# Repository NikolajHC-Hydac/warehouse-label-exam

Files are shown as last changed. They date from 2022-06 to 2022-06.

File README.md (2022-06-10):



<!-- PROJECT LOGO -->
<br />
<div align="center">
  <a href="https://github.com/HydacDK/New-Warehouse-Lables/tree/Prototype4">
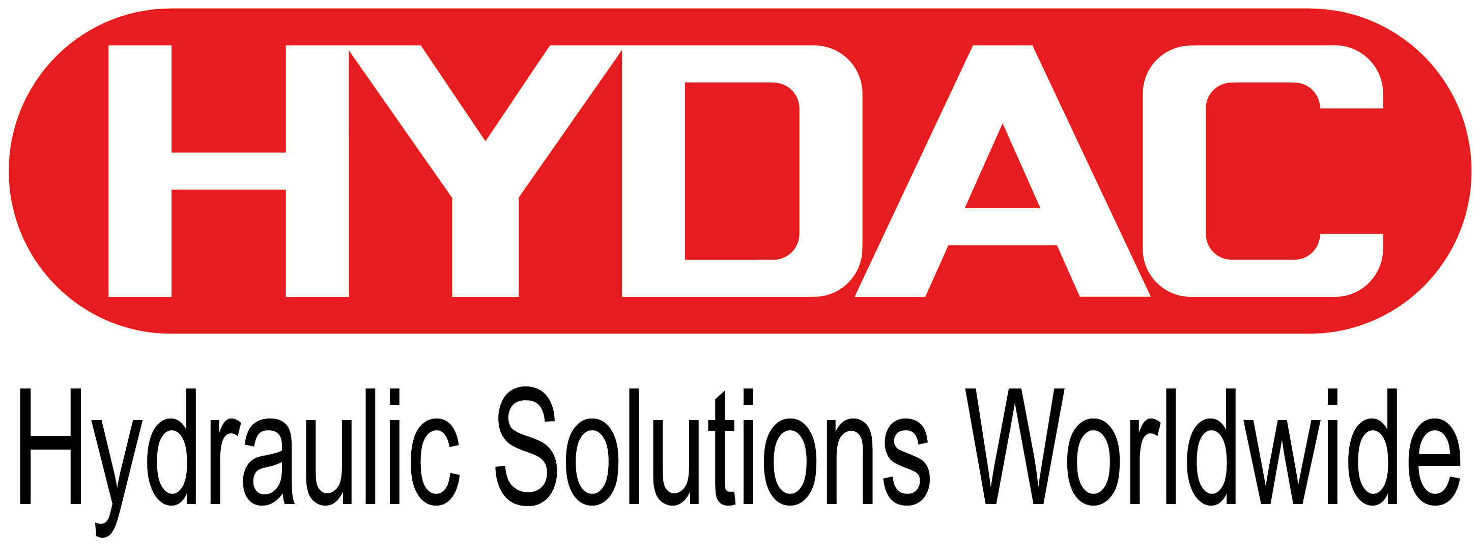
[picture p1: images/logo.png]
    
  </a>

<h3 align="center">Hydac DK Digital 1.0</h3>

  <p align="center">
    Box divided storage system controlled with buttons 
    <br />
    <a href="https://github.com/HydacDK/New-Warehouse-Lables/tree/Prototype4"><strong>Explore the docs »</strong></a>
    <br />
    <br />
    <a href="https://github.com/HydacDK/New-Warehouse-Lables/tree/Prototype4">View Demo</a>
    ·
    <a href="https://github.com/HydacDK/New-Warehouse-Lables/tree/Prototype4/issues">Report Bug</a>
    ·
    <a href="https://github.com/HydacDK/New-Warehouse-Lables/tree/Prototype4/issues">Request Feature</a>
  </p>
</div>

<!-- TABLE OF CONTENTS -->
<details>
  <summary>Table of Contents</summary>
  <ol>
    <li>
      <a href="#about-the-project">About The Project</a>
      <ul>
        <li><a href="#built-with">Built With</a></li>
      </ul>
    </li>
    <li>
      <a href="#getting-started">Getting Started</a>
      <ul>
        <li><a href="#prerequisites">Prerequisites</a></li>
        <li><a href="#installation">Installation</a></li>
      </ul>
    </li>
    <li><a href="#usage">Usage</a></li>
    <li><a href="#roadmap">Roadmap</a></li>
    <li><a href="#contact">Contact</a></li>
  </ol>
</details>

<!-- ABOUT THE PROJECT -->
## About The Project

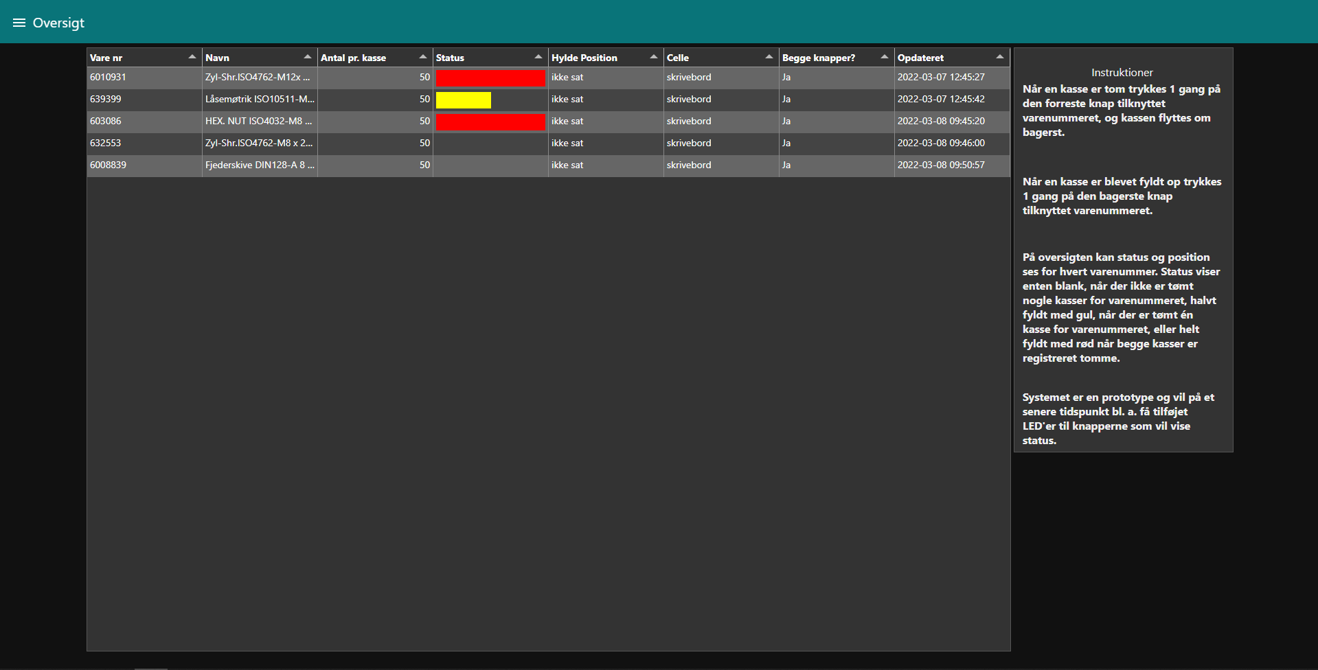
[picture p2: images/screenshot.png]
Product Name Screen Shot
[](http://localhost:1880/ui)

A simple box divided storage system, where two similar boxes with goods are placed on shelves. Buttons are placed on the front and back of the shelves, 2 push buttons for each pair of boxes. When a box is empty, the user presses the "order" on the front of the shelf, and the system notes on the reorder list that the box needs to be refilled. Once a week, the purchasing department will get a list of what c-items (bolts, washers and nuts) that needs to be ordered

Part goal:
C-items (bolts, washers and nuts) are ordered semi automatically by the user, system notes on the reorder list and sends it to the purchasing department weekly. Goods are stocked directly on the shelf.

Goal:
C-items (bolts, washers and nuts) ordered semi automatically by the user, and is sent directly to the distributor of said item. Items stocked directly on the shelf, and ready to use, without the purchasing department using resources on the process. Every month, the purchasing department will receive an invoice, while responsibility for the stock is outsourced to the user.

Gain:
It provides gain on all shelves: Purchasing, finance and user have fewer hours of administration in connection with ordering, invoicing, status, etc. Warehouse spends less time on transport to and from the warehouse and less time on searching for the goods. In addition, the standard program always contains the relevant items in appropriate quantities, and we can therefore cut back on both purchasing and stock binding.

<p align="right">(<a href="#top">back to top</a>)</p>

### Built With

* [Node-red](https://nodered.org/)
* [C++](https://isocpp.org/)
* [SQLite](https://www.sqlite.org/index.html)

<p align="right">(<a href="#top">back to top</a>)</p>

<!-- GETTING STARTED -->
## Getting Started

To get a local copy up and running follow these simple steps.

### Prerequisites

#### Debian and ubuntu based linux distributions  

* Node.js / npm
  ```sh
  # Using Ubuntu  
  curl -fsSL https://deb.nodesource.com/setup_14.x | sudo -E bash -
  sudo apt-get install -y nodejs

  # Using Debian, as root
  curl -fsSL https://deb.nodesource.com/setup_14.x | bash -
  apt-get install -y nodejs
  ```

* Node-red
  ```sh
  sudo npm install -g --unsafe-perm node-red
  ```  

#### Windows

* Node.js
  ```markdown
  Download a 64 or 32 bit version of node.js at [https://nodejs.org](https://nodejs.org/download/release/v14.19.1/)  
  Run the downloaded MSI file.  
    
  Once installed, open a command prompt and run the following command to ensure Node.js and npm are installed correctly.

  Using Powershell: node --version; npm --version

  Using cmd: node --version && npm --version
  ```  

* Node-red
  ```sh
  npm install -g --unsafe-perm node-red
  ```

### Installation

1. Clone the repo
   ```sh
   git clone https://github.com/HydacDK/New-Warehouse-Lables/tree/Prototype4.git
   ```
2. Build and upload esp32 code to control board 
3. Start node-red
    ```sh
    node-red
    ```
4. Import the "Flows.json" file using the node-red GUI
5. Install missing node-red modules
6. Set up mqtt server in the "MQTT" flow
7. In the "Database" flow, point the sqlite and watch nodes to the location of warehouselabels.db
8. Go to http://localhost:1880/ui, or wherever your node-red instance is hosted, enter the setup page, and add the email you want to receive updates on.

<p align="right">(<a href="#top">back to top</a>)</p>

<!-- USAGE EXAMPLES -->
## Usage

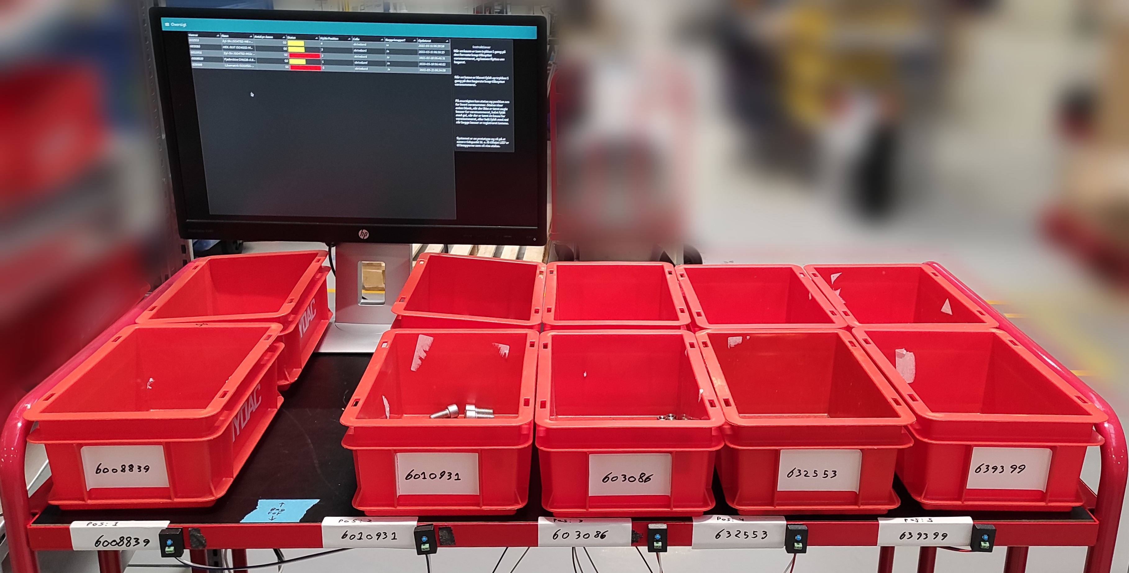
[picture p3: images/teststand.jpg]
TestStand


Buttons are placed in the front of every box pair on shelves, as well as behind them.  
Product numbers are then added to the database, and paired with their respective buttons, either by manually adding them using the setup page in the UI, or by importing them using a CSV file.  
When a box has been emptied, the user presses the matching front button once, and puts the box back in the back of the shelf.  
When the boxes are refilled, the user that is refilling the box, presses the matching button on the back of the shelf, to indicate to the system that the box has been filled again.

_For more examples, please refer to the [Documentation](https://example.com)_

<p align="right">(<a href="#top">back to top</a>)</p>

<!-- ROADMAP -->
## Roadmap

- [x] LED's on front buttons, showing the inventory status to the user
- [x] Automated opening of the UI after a system reset
- [x] Control board revision 4 PCB
    - [x] Design
    - [x] Order
    - [ ] Test
- [x] Buttons PCB
    - [x] Design
    - [x] Order
    - [x] Test

See the [open issues](https://github.com/HydacDK/New-Warehouse-Lables/issues) for a full list of proposed features (and known issues).

<p align="right">(<a href="#top">back to top</a>)</p>

<!-- CONTACT -->
## Contact

Linkedin: Nikolaj Hult-Christensen - [/in/nikolajhult](https://linkedin.com/in/nikolajhult)  
Email: Nikolaj.Hult-Christensen@hydac.dk  
Element: @hultn:hydac.com

Project Link: [https://github.com/HydacDK/New-Warehouse-Lables/tree/Prototype4](https://github.com/HydacDK/New-Warehouse-Lables/tree/Prototype4)

<p align="right">(<a href="#top">back to top</a>)</p>

<!-- MARKDOWN LINKS & IMAGES -->
<!-- https://www.markdownguide.org/basic-syntax/#reference-style-links -->
[contributors-shield]: https://img.shields.io/github/contributors/HydacDK/New-WarehouseLabels.svg?style=for-the-badge
[contributors-url]: https://github.com/HydacDK/New-WarehouseLabels/graphs/contributors
[forks-shield]: https://img.shields.io/github/forks/HydacDK/New-Warehouse-Lables/tree/Prototype4.svg?style=for-the-badge
[forks-url]: https://github.com/HydacDK/New-Warehouse-Lables/tree/Prototype4/network/members
[stars-shield]: https://img.shields.io/github/stars/HydacDK/New-Warehouse-Lables/tree/Prototype4.svg?style=for-the-badge
[stars-url]: https://github.com/HydacDK/New-Warehouse-Lables/tree/Prototype4/stargazers
[issues-shield]: https://img.shields.io/github/issues/HydacDK/New-Warehouse-Lables/tree/Prototype4.svg?style=for-the-badge
[issues-url]: https://github.com/HydacDK/New-Warehouse-Lables/tree/Prototype4/issues
[license-shield]: https://img.shields.io/github/license/HydacDK/New-Warehouse-Lables/tree/Prototype4.svg?style=for-the-badge
[license-url]: https://github.com/HydacDK/New-Warehouse-Lables/tree/Prototype4/blob/master/LICENSE.txt
[linkedin-shield]: https://img.shields.io/badge/-LinkedIn-black.svg?style=for-the-badge&logo=linkedin&colorB=555
[linkedin-url]: https://linkedin.com/in/linkedin_username
[product-screenshot]: images/screenshot.png
[test-stand]: images/teststand.jpg

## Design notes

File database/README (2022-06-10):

Import flows.json into an instance of node-red and deploy

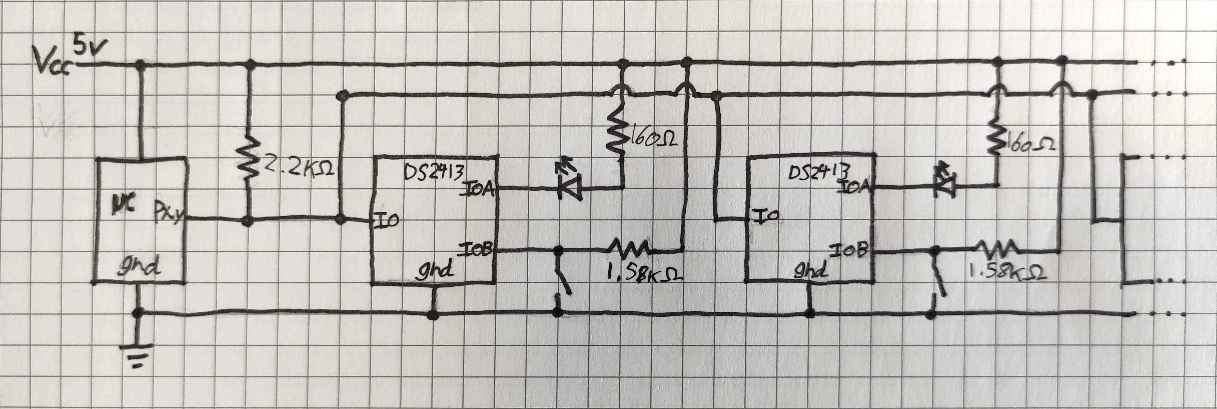
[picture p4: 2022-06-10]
images/onewire_switch_schematic.jpg

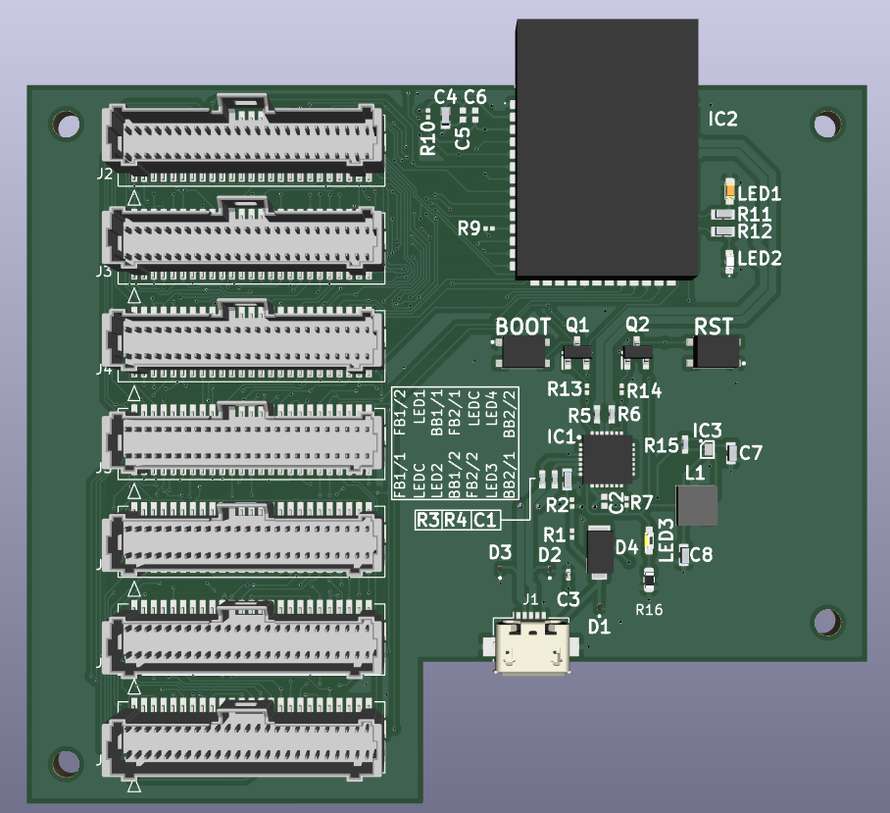
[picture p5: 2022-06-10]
images/pcb_front.png

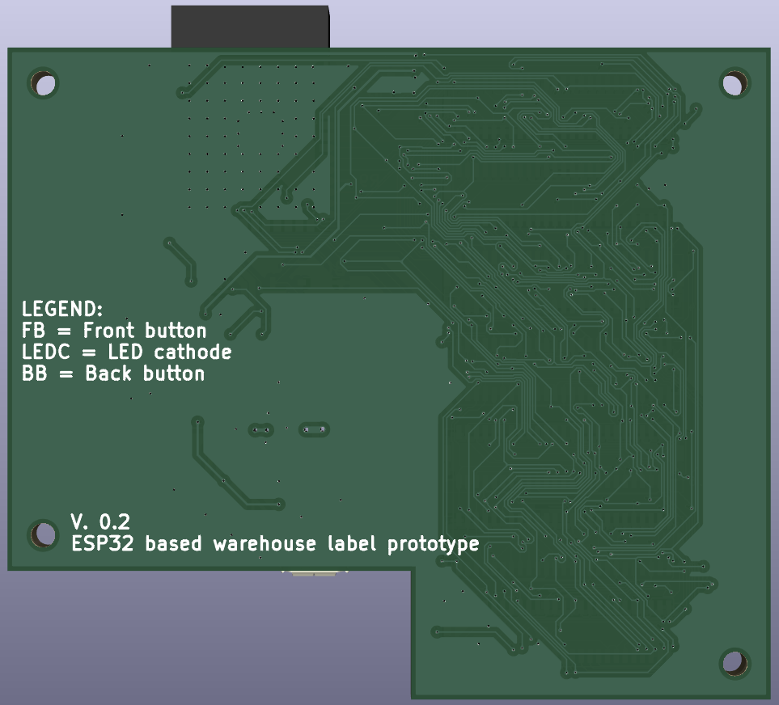
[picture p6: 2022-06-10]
images/pcb_back.png

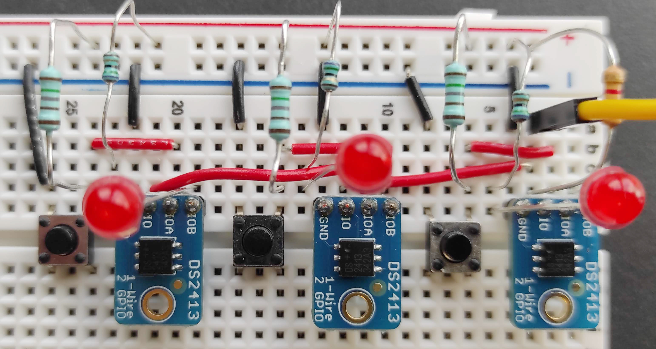
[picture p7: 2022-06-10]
images/onewire_switch_breadboard.jpg

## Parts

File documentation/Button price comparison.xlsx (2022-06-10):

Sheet: Comparison
 | Charlieplexing |  |  |  |  |  | Onewire + neopixel |  |  |  |  |  | Resistor ladder
Buttons: | Button price: | Wires: | Wire length: | Wire price: | charlie price: | Buttons: | Button price: | Wires: | Wire length: | Wire price: | 1-wire price: | Buttons: | Button price: | Wires: | Wire length: | Wire price: | Ladder price: |  |  | Nedenstående priser er kun for komponenter
1 | 8.88 kr. | 3.5 | 5.25 | 3.97 kr. | 12.85 kr. | 1 | 14.52 kr. | 1.5 | 14.3 | 10.81 kr. | 25.32 kr. | 1 | 9.62 kr. | 1.5 | 14.3 | 10.81 kr. | 20.42 kr. | Charlie plexing buttons: |  |  | Ledninger: | Længde: | Pris: | Pris pr. M:
2 | 17.77 kr. | 7 | 10.5 | 7.93 kr. | 25.70 kr. | 2 | 29.04 kr. | 3 | 14.6 | 11.03 kr. | 40.07 kr. | 2 | 19.23 kr. | 3 | 14.6 | 11.03 kr. | 30.26 kr. | Avg wire length: | 1.5 | m | RS PRO 0,13 brun | 100 | 62.55 | 0.6255
3 | 26.65 kr. | 10.5 | 15.75 | 11.90 kr. | 38.55 kr. | 3 | 43.56 kr. | 4.5 | 14.9 | 11.26 kr. | 54.82 kr. | 3 | 28.85 kr. | 4.5 | 14.9 | 11.26 kr. | 40.11 kr. | LED button wires: | 5 |  | RS PRO 0,13 Orange | 100 | 81.99 | 0.8199
4 | 35.53 kr. | 14 | 21 | 15.87 kr. | 51.40 kr. | 4 | 58.08 kr. | 6 | 15.2 | 11.49 kr. | 69.56 kr. | 4 | 38.46 kr. | 6 | 15.2 | 11.49 kr. | 49.95 kr. | LED button price: | 12.462 | kr | RS PRO 0,13 Rød | 100 | 82.15 | 0.8215
5 | 44.42 kr. | 17.5 | 26.25 | 19.84 kr. | 64.25 kr. | 5 | 72.60 kr. | 7.5 | 15.5 | 11.71 kr. | 84.31 kr. | 5 | 48.08 kr. | 7.5 | 15.5 | 11.71 kr. | 59.79 kr. | Button wires: | 2
6 | 53.30 kr. | 21 | 31.5 | 23.80 kr. | 77.10 kr. | 6 | 87.11 kr. | 9 | 15.8 | 11.94 kr. | 99.05 kr. | 6 | 57.70 kr. | 9 | 15.8 | 11.94 kr. | 69.64 kr. | Button price: | 5.30472 | kr | Avg: | 100 | 75.56 | 0.76
7 | 62.18 kr. | 24.5 | 36.75 | 27.77 kr. | 89.95 kr. | 7 | 101.63 kr. | 10.5 | 16.1 | 12.17 kr. | 113.80 kr. | 7 | 67.31 kr. | 10.5 | 16.1 | 12.17 kr. | 79.48 kr. | Avg wires: | 3.5
8 | 71.07 kr. | 28 | 42 | 31.74 kr. | 102.80 kr. | 8 | 116.15 kr. | 12 | 16.4 | 12.39 kr. | 128.55 kr. | 8 | 76.93 kr. | 12 | 16.4 | 12.39 kr. | 89.32 kr. | Avg button price: | 8.88336 | kr
9 | 79.95 kr. | 31.5 | 47.25 | 35.70 kr. | 115.65 kr. | 9 | 130.67 kr. | 13.5 | 16.7 | 12.62 kr. | 143.29 kr. | 9 | 86.55 kr. | 13.5 | 16.7 | 12.62 kr. | 99.16 kr.
10 | 88.83 kr. | 35 | 52.5 | 39.67 kr. | 128.50 kr. | 10 | 145.19 kr. | 15 | 17 | 12.85 kr. | 158.04 kr. | 10 | 96.16 kr. | 15 | 17 | 12.85 kr. | 109.01 kr.
11 | 97.72 kr. | 38.5 | 57.75 | 43.64 kr. | 141.35 kr. | 11 | 159.71 kr. | 16.5 | 17.3 | 13.07 kr. | 172.78 kr. | 11 | 105.78 kr. | 16.5 | 17.3 | 13.07 kr. | 118.85 kr.
12 | 106.60 kr. | 42 | 63 | 47.60 kr. | 154.21 kr. | 12 | 174.23 kr. | 18 | 17.6 | 13.30 kr. | 187.53 kr. | 12 | 115.39 kr. | 18 | 17.6 | 13.30 kr. | 128.69 kr.
13 | 115.48 kr. | 45.5 | 68.25 | 51.57 kr. | 167.06 kr. | 13 | 188.75 kr. | 19.5 | 17.9 | 13.53 kr. | 202.27 kr. | 13 | 125.01 kr. | 19.5 | 17.9 | 13.53 kr. | 138.54 kr. | Onewire + neopixel:
14 | 124.37 kr. | 49 | 73.5 | 55.54 kr. | 179.91 kr. | 14 | 203.27 kr. | 21 | 18.2 | 13.75 kr. | 217.02 kr. | 14 | 134.63 kr. | 21 | 18.2 | 13.75 kr. | 148.38 kr. | Avg wire length: | 0.20 | m
15 | 133.25 kr. | 52.5 | 78.75 | 59.51 kr. | 192.76 kr. | 15 | 217.79 kr. | 22.5 | 18.5 | 13.98 kr. | 231.77 kr. | 15 | 144.24 kr. | 22.5 | 18.5 | 13.98 kr. | 158.22 kr. | LED button wires: | 2
16 | 142.13 kr. | 56 | 84 | 63.47 kr. | 205.61 kr. | 16 | 232.31 kr. | 24 | 18.8 | 14.21 kr. | 246.51 kr. | 16 | 153.86 kr. | 24 | 18.8 | 14.21 kr. | 168.07 kr. | LED button price: | 19.06128 | kr
17 | 151.02 kr. | 59.5 | 89.25 | 67.44 kr. | 218.46 kr. | 17 | 246.83 kr. | 25.5 | 19.1 | 14.43 kr. | 261.26 kr. | 17 | 163.48 kr. | 25.5 | 19.1 | 14.43 kr. | 177.91 kr. | Button wires: | 1
18 | 159.90 kr. | 63 | 94.5 | 71.41 kr. | 231.31 kr. | 18 | 261.34 kr. | 27 | 19.4 | 14.66 kr. | 276.00 kr. | 18 | 173.09 kr. | 27 | 19.4 | 14.66 kr. | 187.75 kr. | Button price: | 9.97704 | kr
19 | 168.78 kr. | 66.5 | 99.75 | 75.37 kr. | 244.16 kr. | 19 | 275.86 kr. | 28.5 | 19.7 | 14.89 kr. | 290.75 kr. | 19 | 182.71 kr. | 28.5 | 19.7 | 14.89 kr. | 197.59 kr. | Avg wires: | 1.5
20 | 177.67 kr. | 70 | 105 | 79.34 kr. | 257.01 kr. | 20 | 290.38 kr. | 30 | 20 | 15.11 kr. | 305.50 kr. | 20 | 192.32 kr. | 30 | 20 | 15.11 kr. | 207.44 kr. | Avg button price: | 14.51916 | kr
21 | 186.55 kr. | 73.5 | 110.25 | 83.31 kr. | 269.86 kr. | 21 | 304.90 kr. | 31.5 | 20.3 | 15.34 kr. | 320.24 kr. | 21 | 201.94 kr. | 31.5 | 20.3 | 15.34 kr. | 217.28 kr. | Fixed amount of wire | 14 | ca. 14 meter ledning som skal trækkes x1 pr. Reol (GND)
22 | 195.43 kr. | 77 | 115.5 | 87.28 kr. | 282.71 kr. | 22 | 319.42 kr. | 33 | 20.6 | 15.57 kr. | 334.99 kr. | 22 | 211.56 kr. | 33 | 20.6 | 15.57 kr. | 227.12 kr.
23 | 204.32 kr. | 80.5 | 120.75 | 91.24 kr. | 295.56 kr. | 23 | 333.94 kr. | 34.5 | 20.9 | 15.79 kr. | 349.73 kr. | 23 | 221.17 kr. | 34.5 | 20.9 | 15.79 kr. | 236.97 kr.
24 | 213.20 kr. | 84 | 126 | 95.21 kr. | 308.41 kr. | 24 | 348.46 kr. | 36 | 21.2 | 16.02 kr. | 364.48 kr. | 24 | 230.79 kr. | 36 | 21.2 | 16.02 kr. | 246.81 kr. | Resistor ladder + neopixel:
25 | 222.08 kr. | 87.5 | 131.25 | 99.18 kr. | 321.26 kr. | 25 | 362.98 kr. | 37.5 | 21.5 | 16.25 kr. | 379.23 kr. | 25 | 240.41 kr. | 37.5 | 21.5 | 16.25 kr. | 256.65 kr. | Avg wire length: | 0.20 | m
26 | 230.97 kr. | 91 | 136.5 | 103.14 kr. | 334.11 kr. | 26 | 377.50 kr. | 39 | 21.8 | 16.47 kr. | 393.97 kr. | 26 | 250.02 kr. | 39 | 21.8 | 16.47 kr. | 266.49 kr. | LED button wires: | 2
27 | 239.85 kr. | 94.5 | 141.75 | 107.11 kr. | 346.96 kr. | 27 | 392.02 kr. | 40.5 | 22.1 | 16.70 kr. | 408.72 kr. | 27 | 259.64 kr. | 40.5 | 22.1 | 16.70 kr. | 276.34 kr. | LED button price: | 14.15832 | kr
28 | 248.73 kr. | 98 | 147 | 111.08 kr. | 359.81 kr. | 28 | 406.54 kr. | 42 | 22.4 | 16.93 kr. | 423.46 kr. | 28 | 269.25 kr. | 42 | 22.4 | 16.93 kr. | 286.18 kr. | Button wires: | 1
29 | 257.62 kr. | 101.5 | 152.25 | 115.05 kr. | 372.66 kr. | 29 | 421.06 kr. | 43.5 | 22.7 | 17.15 kr. | 438.21 kr. | 29 | 278.87 kr. | 43.5 | 22.7 | 17.15 kr. | 296.02 kr. | Button price: | 5.07408 | kr
30 | 266.50 kr. | 105 | 157.5 | 119.01 kr. | 385.51 kr. | 30 | 435.57 kr. | 45 | 23 | 17.38 kr. | 452.95 kr. | 30 | 288.49 kr. | 45 | 23 | 17.38 kr. | 305.87 kr. | Avg wires: | 1.5
31 | 275.38 kr. | 108.5 | 162.75 | 122.98 kr. | 398.36 kr. | 31 | 450.09 kr. | 46.5 | 23.3 | 17.61 kr. | 467.70 kr. | 31 | 298.10 kr. | 46.5 | 23.3 | 17.61 kr. | 315.71 kr. | Avg button price: | 9.6162 | kr
32 | 284.27 kr. | 112 | 168 | 126.95 kr. | 411.21 kr. | 32 | 464.61 kr. | 48 | 23.6 | 17.83 kr. | 482.45 kr. | 32 | 307.72 kr. | 48 | 23.6 | 17.83 kr. | 325.55 kr. | Fixed amount of wire | 14 | ca. 14 meter ledning som skal trækkes x1 pr. Reol (GND)
33 | 293.15 kr. | 115.5 | 173.25 | 130.91 kr. | 424.06 kr. | 33 | 479.13 kr. | 49.5 | 23.9 | 18.06 kr. | 497.19 kr. | 33 | 317.33 kr. | 49.5 | 23.9 | 18.06 kr. | 335.39 kr.
34 | 302.03 kr. | 119 | 178.5 | 134.88 kr. | 436.91 kr. | 34 | 493.65 kr. | 51 | 24.2 | 18.29 kr. | 511.94 kr. | 34 | 326.95 kr. | 51 | 24.2 | 18.29 kr. | 345.24 kr.
35 | 310.92 kr. | 122.5 | 183.75 | 138.85 kr. | 449.77 kr. | 35 | 508.17 kr. | 52.5 | 24.5 | 18.51 kr. | 526.68 kr. | 35 | 336.57 kr. | 52.5 | 24.5 | 18.51 kr. | 355.08 kr.
36 | 319.80 kr. | 126 | 189 | 142.81 kr. | 462.62 kr. | 36 | 522.69 kr. | 54 | 24.8 | 18.74 kr. | 541.43 kr. | 36 | 346.18 kr. | 54 | 24.8 | 18.74 kr. | 364.92 kr.
37 | 328.68 kr. | 129.5 | 194.25 | 146.78 kr. | 475.47 kr. | 37 | 537.21 kr. | 55.5 | 25.1 | 18.97 kr. | 556.18 kr. | 37 | 355.80 kr. | 55.5 | 25.1 | 18.97 kr. | 374.77 kr.
38 | 337.57 kr. | 133 | 199.5 | 150.75 kr. | 488.32 kr. | 38 | 551.73 kr. | 57 | 25.4 | 19.19 kr. | 570.92 kr. | 38 | 365.42 kr. | 57 | 25.4 | 19.19 kr. | 384.61 kr.
39 | 346.45 kr. | 136.5 | 204.75 | 154.72 kr. | 501.17 kr. | 39 | 566.25 kr. | 58.5 | 25.7 | 19.42 kr. | 585.67 kr. | 39 | 375.03 kr. | 58.5 | 25.7 | 19.42 kr. | 394.45 kr.
40 | 355.33 kr. | 140 | 210 | 158.68 kr. | 514.02 kr. | 40 | 580.77 kr. | 60 | 26 | 19.65 kr. | 600.41 kr. | 40 | 384.65 kr. | 60 | 26 | 19.65 kr. | 404.29 kr.
41 | 364.22 kr. | 143.5 | 215.25 | 162.65 kr. | 526.87 kr. | 41 | 595.29 kr. | 61.5 | 26.3 | 19.87 kr. | 615.16 kr. | 41 | 394.26 kr. | 61.5 | 26.3 | 19.87 kr. | 414.14 kr.
42 | 373.10 kr. | 147 | 220.5 | 166.62 kr. | 539.72 kr. | 42 | 609.80 kr. | 63 | 26.6 | 20.10 kr. | 629.90 kr. | 42 | 403.88 kr. | 63 | 26.6 | 20.10 kr. | 423.98 kr.
43 | 381.98 kr. | 150.5 | 225.75 | 170.58 kr. | 552.57 kr. | 43 | 624.32 kr. | 64.5 | 26.9 | 20.33 kr. | 644.65 kr. | 43 | 413.50 kr. | 64.5 | 26.9 | 20.33 kr. | 433.82 kr.
44 | 390.87 kr. | 154 | 231 | 174.55 kr. | 565.42 kr. | 44 | 638.84 kr. | 66 | 27.2 | 20.55 kr. | 659.40 kr. | 44 | 423.11 kr. | 66 | 27.2 | 20.55 kr. | 443.67 kr.
45 | 399.75 kr. | 157.5 | 236.25 | 178.52 kr. | 578.27 kr. | 45 | 653.36 kr. | 67.5 | 27.5 | 20.78 kr. | 674.14 kr. | 45 | 432.73 kr. | 67.5 | 27.5 | 20.78 kr. | 453.51 kr.
46 | 408.63 kr. | 161 | 241.5 | 182.49 kr. | 591.12 kr. | 46 | 667.88 kr. | 69 | 27.8 | 21.01 kr. | 688.89 kr. | 46 | 442.35 kr. | 69 | 27.8 | 21.01 kr. | 463.35 kr.
47 | 417.52 kr. | 164.5 | 246.75 | 186.45 kr. | 603.97 kr. | 47 | 682.40 kr. | 70.5 | 28.1 | 21.23 kr. | 703.63 kr. | 47 | 451.96 kr. | 70.5 | 28.1 | 21.23 kr. | 473.19 kr.
48 | 426.40 kr. | 168 | 252 | 190.42 kr. | 616.82 kr. | 48 | 696.92 kr. | 72 | 28.4 | 21.46 kr. | 718.38 kr. | 48 | 461.58 kr. | 72 | 28.4 | 21.46 kr. | 483.04 kr.
49 | 435.28 kr. | 171.5 | 257.25 | 194.39 kr. | 629.67 kr. | 49 | 711.44 kr. | 73.5 | 28.7 | 21.69 kr. | 733.13 kr. | 49 | 471.19 kr. | 73.5 | 28.7 | 21.69 kr. | 492.88 kr.
50 | 444.17 kr. | 175 | 262.5 | 198.35 kr. | 642.52 kr. | 50 | 725.96 kr. | 75 | 29 | 21.91 kr. | 747.87 kr. | 50 | 480.81 kr. | 75 | 29 | 21.91 kr. | 502.72 kr.
51 | 453.05 kr. | 178.5 | 267.75 | 202.32 kr. | 655.37 kr. | 51 | 740.48 kr. | 76.5 | 29.3 | 22.14 kr. | 762.62 kr. | 51 | 490.43 kr. | 76.5 | 29.3 | 22.14 kr. | 512.57 kr.
52 | 461.93 kr. | 182 | 273 | 206.29 kr. | 668.22 kr. | 52 | 755.00 kr. | 78 | 29.6 | 22.37 kr. | 777.36 kr. | 52 | 500.04 kr. | 78 | 29.6 | 22.37 kr. | 522.41 kr.
53 | 470.82 kr. | 185.5 | 278.25 | 210.25 kr. | 681.07 kr. | 53 | 769.52 kr. | 79.5 | 29.9 | 22.59 kr. | 792.11 kr. | 53 | 509.66 kr. | 79.5 | 29.9 | 22.59 kr. | 532.25 kr.
54 | 479.70 kr. | 189 | 283.5 | 214.22 kr. | 693.92 kr. | 54 | 784.03 kr. | 81 | 30.2 | 22.82 kr. | 806.85 kr. | 54 | 519.27 kr. | 81 | 30.2 | 22.82 kr. | 542.09 kr.
55 | 488.58 kr. | 192.5 | 288.75 | 218.19 kr. | 706.77 kr. | 55 | 798.55 kr. | 82.5 | 30.5 | 23.05 kr. | 821.60 kr. | 55 | 528.89 kr. | 82.5 | 30.5 | 23.05 kr. | 551.94 kr.
56 | 497.47 kr. | 196 | 294 | 222.16 kr. | 719.62 kr. | 56 | 813.07 kr. | 84 | 30.8 | 23.27 kr. | 836.35 kr. | 56 | 538.51 kr. | 84 | 30.8 | 23.27 kr. | 561.78 kr.
57 | 506.35 kr. | 199.5 | 299.25 | 226.12 kr. | 732.47 kr. | 57 | 827.59 kr. | 85.5 | 31.1 | 23.50 kr. | 851.09 kr. | 57 | 548.12 kr. | 85.5 | 31.1 | 23.50 kr. | 571.62 kr.
58 | 515.23 kr. | 203 | 304.5 | 230.09 kr. | 745.33 kr. | 58 | 842.11 kr. | 87 | 31.4 | 23.73 kr. | 865.84 kr. | 58 | 557.74 kr. | 87 | 31.4 | 23.73 kr. | 581.47 kr.
59 | 524.12 kr. | 206.5 | 309.75 | 234.06 kr. | 758.18 kr. | 59 | 856.63 kr. | 88.5 | 31.7 | 23.95 kr. | 880.58 kr. | 59 | 567.36 kr. | 88.5 | 31.7 | 23.95 kr. | 591.31 kr.
60 | 533.00 kr. | 210 | 315 | 238.02 kr. | 771.03 kr. | 60 | 871.15 kr. | 90 | 32 | 24.18 kr. | 895.33 kr. | 60 | 576.97 kr. | 90 | 32 | 24.18 kr. | 601.15 kr.
61 | 541.88 kr. | 213.5 | 320.25 | 241.99 kr. | 783.88 kr. | 61 | 885.67 kr. | 91.5 | 32.3 | 24.41 kr. | 910.08 kr. | 61 | 586.59 kr. | 91.5 | 32.3 | 24.41 kr. | 611.00 kr.
62 | 550.77 kr. | 217 | 325.5 | 245.96 kr. | 796.73 kr. | 62 | 900.19 kr. | 93 | 32.6 | 24.63 kr. | 924.82 kr. | 62 | 596.20 kr. | 93 | 32.6 | 24.63 kr. | 620.84 kr.
63 | 559.65 kr. | 220.5 | 330.75 | 249.93 kr. | 809.58 kr. | 63 | 914.71 kr. | 94.5 | 32.9 | 24.86 kr. | 939.57 kr. | 63 | 605.82 kr. | 94.5 | 32.9 | 24.86 kr. | 630.68 kr.
64 | 568.54 kr. | 224 | 336 | 253.89 kr. | 822.43 kr. | 64 | 929.23 kr. | 96 | 33.2 | 25.09 kr. | 954.31 kr. | 64 | 615.44 kr. | 96 | 33.2 | 25.09 kr. | 640.52 kr.
65 | 577.42 kr. | 227.5 | 341.25 | 257.86 kr. | 835.28 kr. | 65 | 943.75 kr. | 97.5 | 33.5 | 25.31 kr. | 969.06 kr. | 65 | 625.05 kr. | 97.5 | 33.5 | 25.31 kr. | 650.37 kr.
66 | 586.30 kr. | 231 | 346.5 | 261.83 kr. | 848.13 kr. | 66 | 958.26 kr. | 99 | 33.8 | 25.54 kr. | 983.80 kr. | 66 | 634.67 kr. | 99 | 33.8 | 25.54 kr. | 660.21 kr.
67 | 595.19 kr. | 234.5 | 351.75 | 265.79 kr. | 860.98 kr. | 67 | 972.78 kr. | 100.5 | 34.1 | 25.77 kr. | 998.55 kr. | 67 | 644.29 kr. | 100.5 | 34.1 | 25.77 kr. | 670.05 kr.
68 | 604.07 kr. | 238 | 357 | 269.76 kr. | 873.83 kr. | 68 | 987.30 kr. | 102 | 34.4 | 25.99 kr. | 1013.30 kr. | 68 | 653.90 kr. | 102 | 34.4 | 25.99 kr. | 679.90 kr.
69 | 612.95 kr. | 241.5 | 362.25 | 273.73 kr. | 886.68 kr. | 69 | 1001.82 kr. | 103.5 | 34.7 | 26.22 kr. | 1028.04 kr. | 69 | 663.52 kr. | 103.5 | 34.7 | 26.22 kr. | 689.74 kr.
70 | 621.84 kr. | 245 | 367.5 | 277.70 kr. | 899.53 kr. | 70 | 1016.34 kr. | 105 | 35 | 26.45 kr. | 1042.79 kr. | 70 | 673.13 kr. | 105 | 35 | 26.45 kr. | 699.58 kr.
71 | 630.72 kr. | 248.5 | 372.75 | 281.66 kr. | 912.38 kr. | 71 | 1030.86 kr. | 106.5 | 35.3 | 26.67 kr. | 1057.53 kr. | 71 | 682.75 kr. | 106.5 | 35.3 | 26.67 kr. | 709.42 kr.
72 | 639.60 kr. | 252 | 378 | 285.63 kr. | 925.23 kr. | 72 | 1045.38 kr. | 108 | 35.6 | 26.90 kr. | 1072.28 kr. | 72 | 692.37 kr. | 108 | 35.6 | 26.90 kr. | 719.27 kr.
73 | 648.49 kr. | 255.5 | 383.25 | 289.60 kr. | 938.08 kr. | 73 | 1059.90 kr. | 109.5 | 35.9 | 27.13 kr. | 1087.03 kr. | 73 | 701.98 kr. | 109.5 | 35.9 | 27.13 kr. | 729.11 kr.
74 | 657.37 kr. | 259 | 388.5 | 293.56 kr. | 950.93 kr. | 74 | 1074.42 kr. | 111 | 36.2 | 27.35 kr. | 1101.77 kr. | 74 | 711.60 kr. | 111 | 36.2 | 27.35 kr. | 738.95 kr.
75 | 666.25 kr. | 262.5 | 393.75 | 297.53 kr. | 963.78 kr. | 75 | 1088.94 kr. | 112.5 | 36.5 | 27.58 kr. | 1116.52 kr. | 75 | 721.22 kr. | 112.5 | 36.5 | 27.58 kr. | 748.80 kr.
76 | 675.14 kr. | 266 | 399 | 301.50 kr. | 976.63 kr. | 76 | 1103.46 kr. | 114 | 36.8 | 27.81 kr. | 1131.26 kr. | 76 | 730.83 kr. | 114 | 36.8 | 27.81 kr. | 758.64 kr.
77 | 684.02 kr. | 269.5 | 404.25 | 305.46 kr. | 989.48 kr. | 77 | 1117.98 kr. | 115.5 | 37.1 | 28.03 kr. | 1146.01 kr. | 77 | 740.45 kr. | 115.5 | 37.1 | 28.03 kr. | 768.48 kr.
78 | 692.90 kr. | 273 | 409.5 | 309.43 kr. | 1002.33 kr. | 78 | 1132.49 kr. | 117 | 37.4 | 28.26 kr. | 1160.76 kr. | 78 | 750.06 kr. | 117 | 37.4 | 28.26 kr. | 778.32 kr.
79 | 701.79 kr. | 276.5 | 414.75 | 313.40 kr. | 1015.18 kr. | 79 | 1147.01 kr. | 118.5 | 37.7 | 28.49 kr. | 1175.50 kr. | 79 | 759.68 kr. | 118.5 | 37.7 | 28.49 kr. | 788.17 kr.
80 | 710.67 kr. | 280 | 420 | 317.37 kr. | 1028.03 kr. | 80 | 1161.53 kr. | 120 | 38 | 28.71 kr. | 1190.25 kr. | 80 | 769.30 kr. | 120 | 38 | 28.71 kr. | 798.01 kr.
81 | 719.55 kr. | 283.5 | 425.25 | 321.33 kr. | 1040.89 kr. | 81 | 1176.05 kr. | 121.5 | 38.3 | 28.94 kr. | 1204.99 kr. | 81 | 778.91 kr. | 121.5 | 38.3 | 28.94 kr. | 807.85 kr.
82 | 728.44 kr. | 287 | 430.5 | 325.30 kr. | 1053.74 kr. | 82 | 1190.57 kr. | 123 | 38.6 | 29.17 kr. | 1219.74 kr. | 82 | 788.53 kr. | 123 | 38.6 | 29.17 kr. | 817.70 kr.
83 | 737.32 kr. | 290.5 | 435.75 | 329.27 kr. | 1066.59 kr. | 83 | 1205.09 kr. | 124.5 | 38.9 | 29.39 kr. | 1234.48 kr. | 83 | 798.14 kr. | 124.5 | 38.9 | 29.39 kr. | 827.54 kr.
84 | 746.20 kr. | 294 | 441 | 333.23 kr. | 1079.44 kr. | 84 | 1219.61 kr. | 126 | 39.2 | 29.62 kr. | 1249.23 kr. | 84 | 807.76 kr. | 126 | 39.2 | 29.62 kr. | 837.38 kr.
85 | 755.09 kr. | 297.5 | 446.25 | 337.20 kr. | 1092.29 kr. | 85 | 1234.13 kr. | 127.5 | 39.5 | 29.85 kr. | 1263.98 kr. | 85 | 817.38 kr. | 127.5 | 39.5 | 29.85 kr. | 847.22 kr.
86 | 763.97 kr. | 301 | 451.5 | 341.17 kr. | 1105.14 kr. | 86 | 1248.65 kr. | 129 | 39.8 | 30.07 kr. | 1278.72 kr. | 86 | 826.99 kr. | 129 | 39.8 | 30.07 kr. | 857.07 kr.
87 | 772.85 kr. | 304.5 | 456.75 | 345.14 kr. | 1117.99 kr. | 87 | 1263.17 kr. | 130.5 | 40.1 | 30.30 kr. | 1293.47 kr. | 87 | 836.61 kr. | 130.5 | 40.1 | 30.30 kr. | 866.91 kr.
88 | 781.74 kr. | 308 | 462 | 349.10 kr. | 1130.84 kr. | 88 | 1277.69 kr. | 132 | 40.4 | 30.53 kr. | 1308.21 kr. | 88 | 846.23 kr. | 132 | 40.4 | 30.53 kr. | 876.75 kr.
89 | 790.62 kr. | 311.5 | 467.25 | 353.07 kr. | 1143.69 kr. | 89 | 1292.21 kr. | 133.5 | 40.7 | 30.75 kr. | 1322.96 kr. | 89 | 855.84 kr. | 133.5 | 40.7 | 30.75 kr. | 886.60 kr.
90 | 799.50 kr. | 315 | 472.5 | 357.04 kr. | 1156.54 kr. | 90 | 1306.72 kr. | 135 | 41 | 30.98 kr. | 1337.71 kr. | 90 | 865.46 kr. | 135 | 41 | 30.98 kr. | 896.44 kr.
91 | 808.39 kr. | 318.5 | 477.75 | 361.00 kr. | 1169.39 kr. | 91 | 1321.24 kr. | 136.5 | 41.3 | 31.21 kr. | 1352.45 kr. | 91 | 875.07 kr. | 136.5 | 41.3 | 31.21 kr. | 906.28 kr.
92 | 817.27 kr. | 322 | 483 | 364.97 kr. | 1182.24 kr. | 92 | 1335.76 kr. | 138 | 41.6 | 31.43 kr. | 1367.20 kr. | 92 | 884.69 kr. | 138 | 41.6 | 31.43 kr. | 916.12 kr.
93 | 826.15 kr. | 325.5 | 488.25 | 368.94 kr. | 1195.09 kr. | 93 | 1350.28 kr. | 139.5 | 41.9 | 31.66 kr. | 1381.94 kr. | 93 | 894.31 kr. | 139.5 | 41.9 | 31.66 kr. | 925.97 kr.
94 | 835.04 kr. | 329 | 493.5 | 372.91 kr. | 1207.94 kr. | 94 | 1364.80 kr. | 141 | 42.2 | 31.89 kr. | 1396.69 kr. | 94 | 903.92 kr. | 141 | 42.2 | 31.89 kr. | 935.81 kr.
95 | 843.92 kr. | 332.5 | 498.75 | 376.87 kr. | 1220.79 kr. | 95 | 1379.32 kr. | 142.5 | 42.5 | 32.11 kr. | 1411.43 kr. | 95 | 913.54 kr. | 142.5 | 42.5 | 32.11 kr. | 945.65 kr.
96 | 852.80 kr. | 336 | 504 | 380.84 kr. | 1233.64 kr. | 96 | 1393.84 kr. | 144 | 42.8 | 32.34 kr. | 1426.18 kr. | 96 | 923.16 kr. | 144 | 42.8 | 32.34 kr. | 955.50 kr.

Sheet: Charlieplexing
BOM | Without LED |  |  |  | BOM | With LED
 | Component | Amount | Price | Comment |  | Component | Amount | Price | Comment | Udregnet efter priser for 100 stk.
 | 1N4148 | 1 | 0.051 |  |  | 1N4148 | 1 | 0.051
 | Tactile switch | 1 | 0.138 | TS04-66-73-BK-260-SMT |  | Tactile switch | 1 | 0.138 | TS04-66-73-BK-260-SMT
 | Connector | 1 | 0.524 | 501953-0405 |  | bi-color LED | 1 | 0.217 | VLMKE3401-GS18
Total: |  |  | 0.713 |  |  | resistor | 1 | 0.009 | CR0805-JW-750ELF
 |  |  |  |  |  | Connector | 1 | 1.26 | 203558-0807
 |  |  |  |  | Total: |  |  | 1.675

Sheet: 1-wire + neopixel
BOM | Without LED |  |  |  | BOM | With LED
 | Component | Amount | Price | Comment |  | Component | Amount | Price | Comment | Udregnet efter priser for 100 stk.
 | DS28E05R+T | 1 | 0.679 |  |  | DS28E05R+T | 1 | 0.679
 | Tactile switch | 1 | 0.138 | TS04-66-73-BK-260-SMT |  | Tactile switch | 1 | 0.138 | TS04-66-73-BK-260-SMT
 | Connector | 1 | 0.524 | 501953-0405 |  | Neopixel 5050 | 1 | 0.473 | COM-16346
Total: |  |  | 1.341 |  |  | 0.1 UF cap | 1 | 0.012 | CL05B104KP5NNWC
 |  |  |  |  |  | Connector | 1 | 1.26 | 203558-0807
 |  |  |  |  | Total: |  |  | 2.562

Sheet: Resistor ladder + neopixel
BOM | Without LED |  |  |  | BOM | With LED
 | Component | Amount | Price | Comment |  | Component | Amount | Price | Comment | Udregnet efter priser for 100 stk.
 | resistor | 1 | 0.02 | Estimate |  | resistor | 1 | 0.02 | Estimate | Connectors er ikke medregnet I prisen
 | Tactile switch | 1 | 0.138 | TS04-66-73-BK-260-SMT |  | Tactile switch | 1 | 0.138 | TS04-66-73-BK-260-SMT
 | Connector | 1 | 0.524 | 501953-0405 |  | Neopixel 5050 | 1 | 0.473 | COM-16346
Total: |  |  | 0.682 |  |  | 0.1 UF cap | 1 | 0.012 | CL05B104KP5NNWC
 |  |  |  |  |  | Connector | 1 | 1.26 | 203558-0807
 |  |  |  |  | Total: |  |  | 1.903

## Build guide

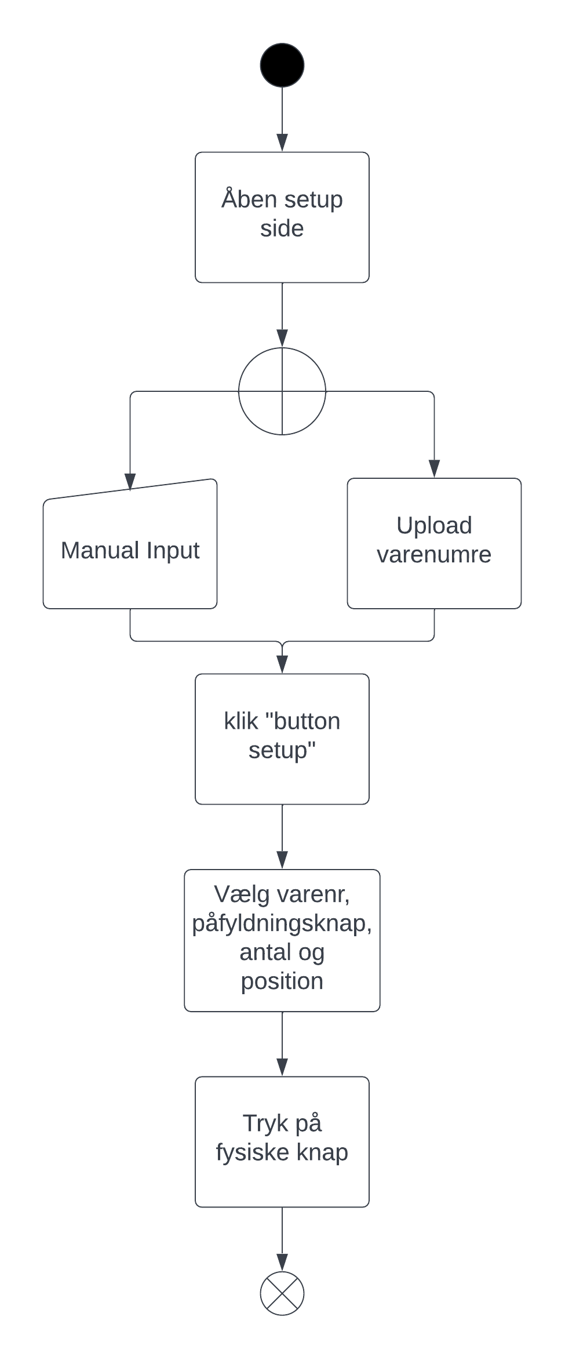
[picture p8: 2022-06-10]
documentation/uml_activity_setup.png

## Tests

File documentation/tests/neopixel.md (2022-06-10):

# neopixel test

## Test build
To test neopixels for addressing LED's, the following breadboard was build:  
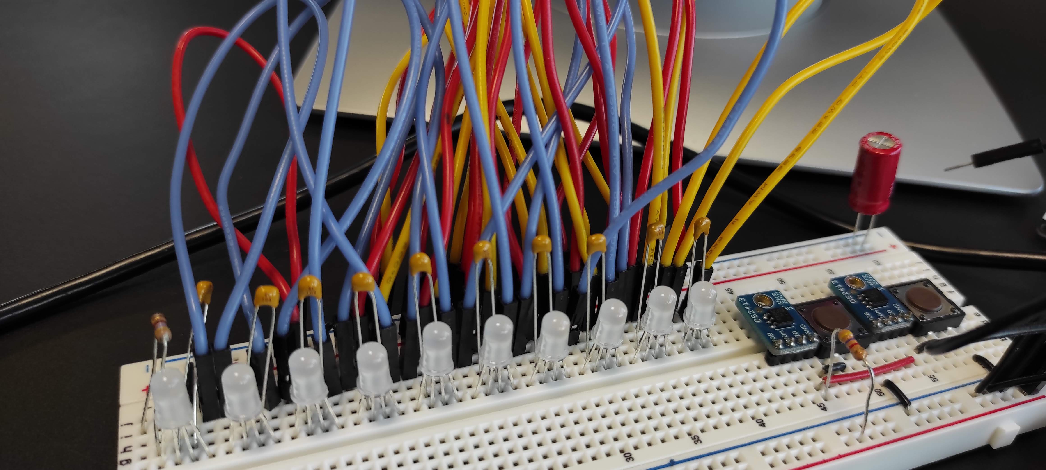
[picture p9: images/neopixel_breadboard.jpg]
Breadboard with neopixels test.

Ten ws2812b LED's were connected in series, with small decoupling capacitors connected between each LED's VDD and ground, as well as a large capacitor connected across the + and - terminals of the DC power supply.  
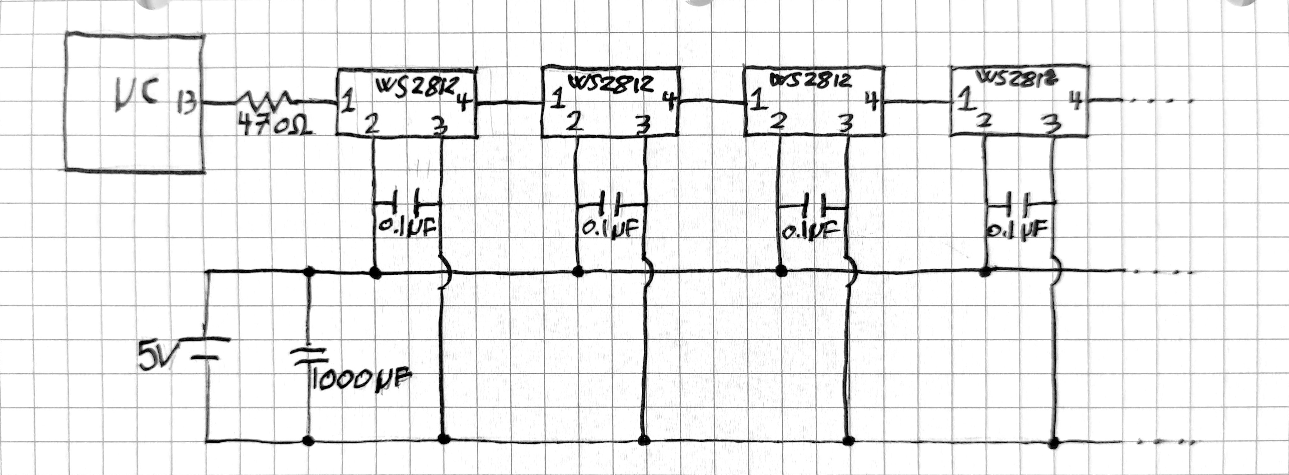
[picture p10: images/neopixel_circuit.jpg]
Circuit diagram showing the resistor ladder test setup


## Test code
The FastLED library was used along with some slightly modified example code to test the neopixels functionality, and to gain familiarity with how they function.  
[See code here](https://github.com/HydacDK/New-Warehouse-Lables/blob/Prototype4/code/tests/Neopixel/src/main.cpp)

## Observations

 - The adafruit_neopixel library was incomplatible with the at the time current version of arduino being used with platformIO. This may be fixed with the newest version of the espressif 32 platform as it has been updated to include arduino 2.0
 - It is easy to address individual LED's with neopixels
 - Wiring is minimal. Aditional components needed is also very small

## Conclusion
Using neopixels for addressing LED's seems like a good fit for the project:

 - Positives:
	 - Cheap
	 - Easy to use
	 - Abundant worldwide stock
	 - Minimal wiring needed
	 - Few components to make work
- Cons:
	- LED's will not have same serial as their respective buttons
	- Will require some setup on first run.

Using neopixels for addressing LED's would significantly cut down on the amount of cables needed compared to charlieplexing, and make the system easily scaleable, with minimal setup required at the start of use.

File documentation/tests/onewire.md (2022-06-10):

# Onewire test

## Test build
To test using the onewire protocol for button identification, the following breadboard was build:  
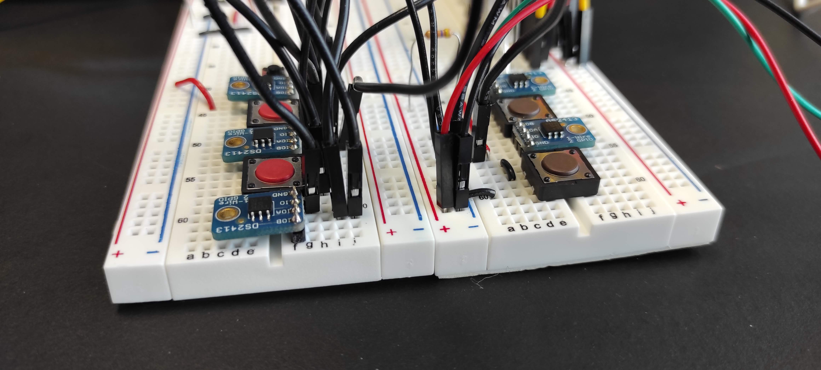
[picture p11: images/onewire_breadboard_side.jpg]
Breadboard with onewire test setup, as seen from the side.

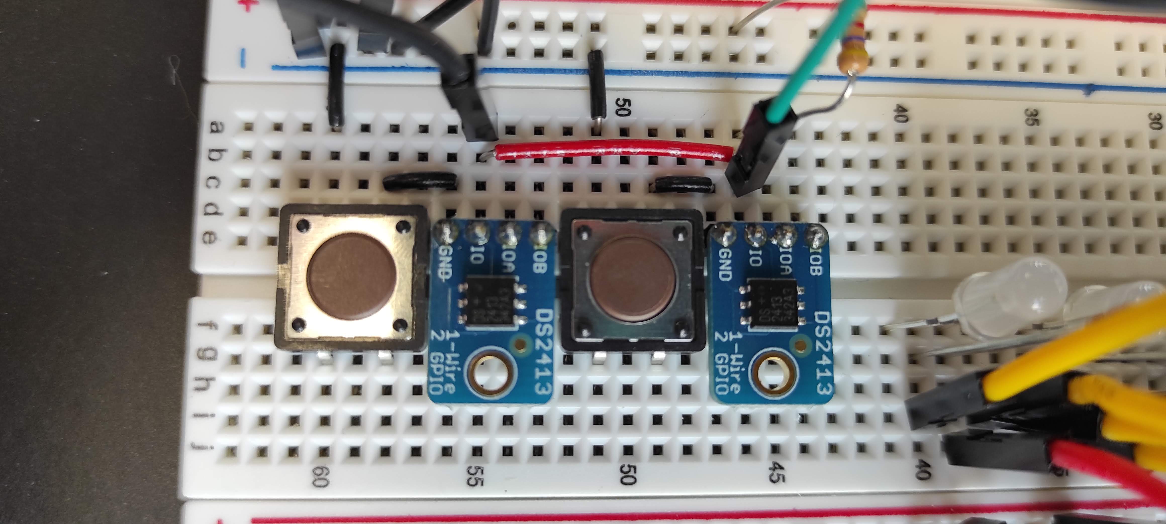
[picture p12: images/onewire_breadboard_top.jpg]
Breadboard with onewire test setup, as seen from the top.

four DS2413 onewire units were connected in series with  each other. These onewire units were connected to GND through a momentary button, only powering them on when the button was being held.  
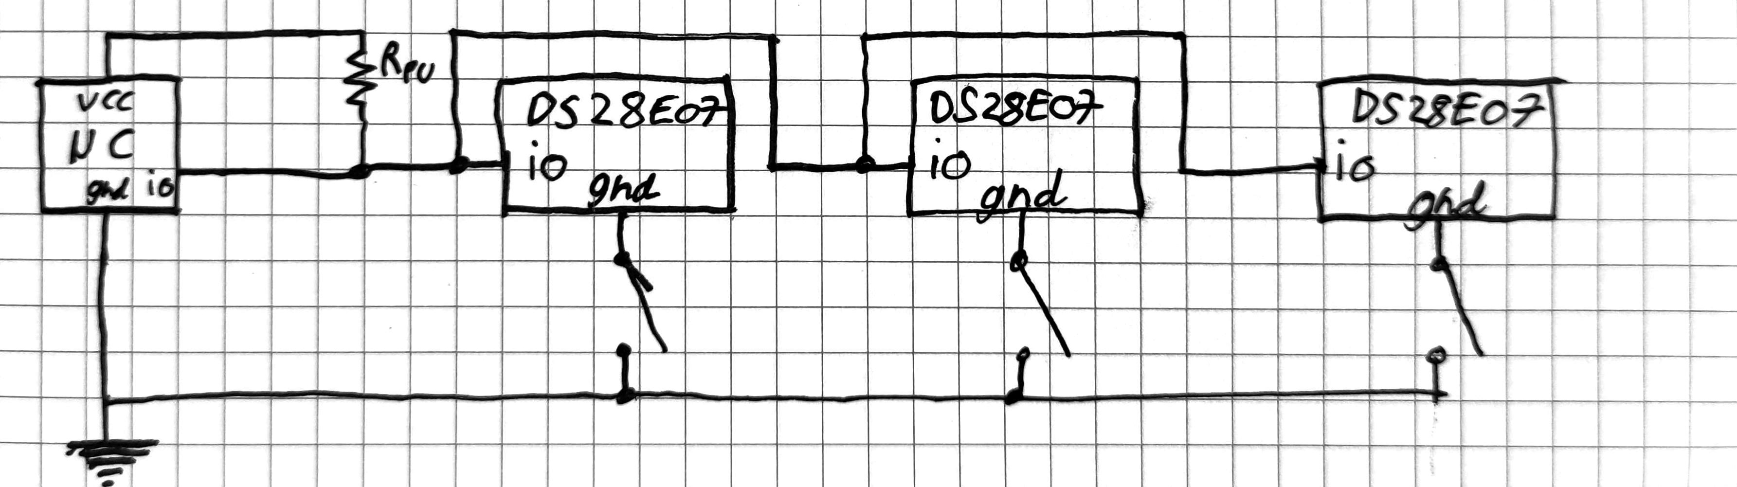
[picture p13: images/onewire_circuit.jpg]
Circuit diagram showing the onewire ladder test setup


## Test code
The following code was written to test the usage of the onewire protocol for button identification:  
    
    #include <Arduino.h>
    #include "OneWireNg_CurrentPlatform.h"

    #define OW_PIN          14

    static OneWireNg *ow = NULL;

    static void printId(const OneWireNg::Id& id) {
        Serial.print(id[0], HEX);
        for (size_t i = 1; i < sizeof(OneWireNg::Id); i++) {
            Serial.print(':');
            Serial.print(id[i], HEX);
        }
        Serial.println();
    }

    void setup() {
        ow = new OneWireNg_CurrentPlatform(OW_PIN, false);
        Serial.begin(115200);
    }

    void loop() {
        OneWireNg::Id id;
        ow->searchReset();
        while (ow->search(id) == OneWireNg::EC_MORE) {
            printId(id);
        }
    }

## Observations

 - Each search where a button is found takes ~15 milliseconds
 - Each search where no button is found takes less than a millisecond
 - Wiring is very simple
 - Only signal and gnd wires need to be used, as vcc is only used to pull up the signal wire
 - Can only be used for buttons, not LED's when used in this way

## Conclusion
Using onewire for addressing buttons seems like a good fit for the project:

 - Positives:
	 - Onewire units that can be used in this way can be as cheap as 0,7 euro a piece.
	 - Easy to use
	 - Decent worldwide stock
	 - Minimal wiring needed
	 - Very fast
	 - No slowdown with more units added
	 - Multiple buttons can be pressed at once (no ghosting)
- Cons:
	- Buttons and LED's will have to be controlled seperately
	- Will require some setup on first run.

Using onewire for addressing buttons would significantly cut down on the amount of cables needed compared to charlieplexing, and make the system easily scaleable, with minimal setup required at the start of use.

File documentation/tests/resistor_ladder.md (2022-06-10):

# Resistor ladder test

## Test build
To test using a resistor ladder for button identification, the following breadboard was build:
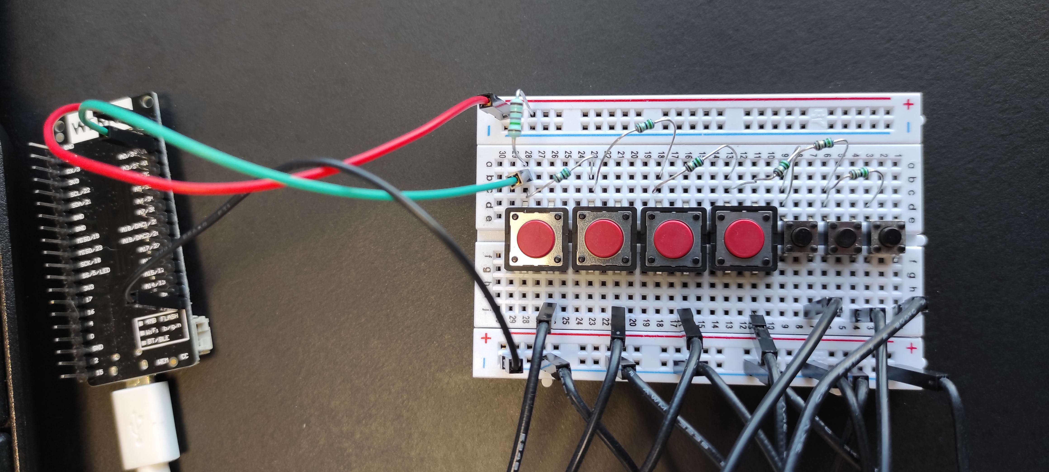
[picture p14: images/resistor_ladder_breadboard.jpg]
Breadboard with resistor ladder test.

Seven button were connected in paralel, with equal value resistors in series between each button.
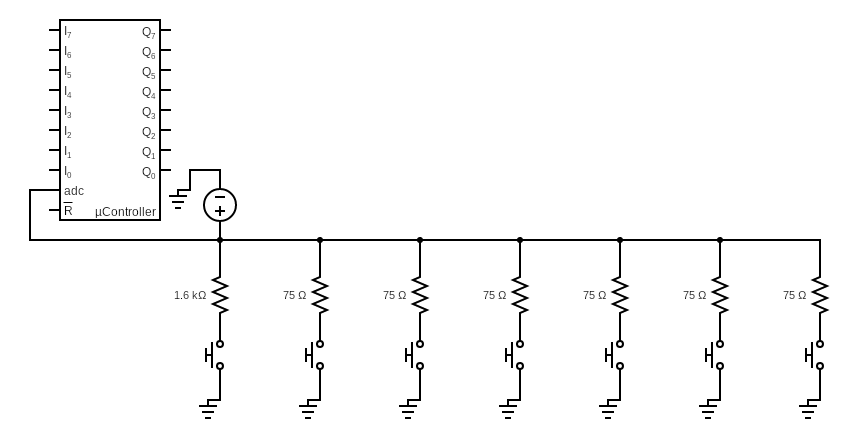
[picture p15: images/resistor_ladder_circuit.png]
Circuit diagram showing the resistor ladder test setup


## Test code
The following code was written to test the usage of a resistor ladder for button identification:

    #include <Arduino.h>
	
	#define INPUT_PIN A0
	
	const int numReadings = 10;
	const int deviation = 50;
	
	int readButton();
	int oldResult;
	bool buttonState;
	int readings = 0;
	int total = 0;
	int average = 0;
	int readingCheck = 0;
	int oldReadingCheck = 0;
	
	void setup() {
	  Serial.begin(9600);
	  pinMode(INPUT_PIN, INPUT);
	  buttonState = false;
	}
	
	void loop() {
	  int result = readButton();
	  delay(100);
	  if (result != 0 && !buttonState){
	    Serial.print(result);
	    Serial.print(" ");
	    Serial.println(average);
		oldResult = result;
	    buttonState = true;
	  }
	}
	
	int readButton() {
	  readingCheck = analogRead(INPUT_PIN);
	  if (abs(oldReadingCheck - readingCheck) > deviation){
	    for (readings = 0; readings <= numReadings; readings++){
	      total = total + analogRead(INPUT_PIN);
	    }
	    average = total / readings;
	    total = 0;
	    oldReadingCheck = readingCheck;
	    if (average > 900){
	      total = 0;
	      buttonState = false;
	      return 0;
	    }
	    if (average == 0) return 1;
	    if (average < 100) return 2;
	    if (average < 270) return 3;
	    if (average < 433) return 4;
	    if (average < 582) return 5;
	    if (average < 720) return 6;
	    if (average < 900) return 7;
	  }
	}

## Observations

 - The use of one resistor value severely limits the amount of buttons that can reliably be operated
	 - The test setup had a std. deviation on readings of ~23, with an ADC tolerance of 40.96 using 1% resistors
	 - Having multiple values of resistors, with logarithmicly increasing resistances will change the voltage scaling from logarithmic to linear, making adjacent ADC values roughly equidistant. This will allow for a much higher amount of buttons connected at once. It will also make it possible to dynamically calculate the corresponding button for any given reading, rather than hard-coding the values.
- Using a higher current limiting resistor will reduce teh current consumed by the system, but will also reduce the difference between readings of individual buttons
- Values in the code had to be manually adjusted, and hardcoded to factor in the real resistance of the resistors.
- Using the average of 10 readings taken after a button had been pushed down seemed to decrease deviations in the ADC values being read, but not signifficantly.

## Conclusion
Using a resistor ladder for button identification has its positives and negatives:

 - Positives:
	 - Each individual button is cheap to produce
	 - Simple electronics
	 - Simple code
	 - Constant polling
- Cons:
	- Many wasted buttons is possible issue
	- Each button can only be used in specific positions

If the resistor ladder method is to be used, then each button needs to have unique resistor values. This is possible to make, but it will either require hand soldering resistors to each button, or if designed with resistors already soldered on, then PCB panels will have wasted buttons on them that are not usable anywhere else, unless a button breaks.

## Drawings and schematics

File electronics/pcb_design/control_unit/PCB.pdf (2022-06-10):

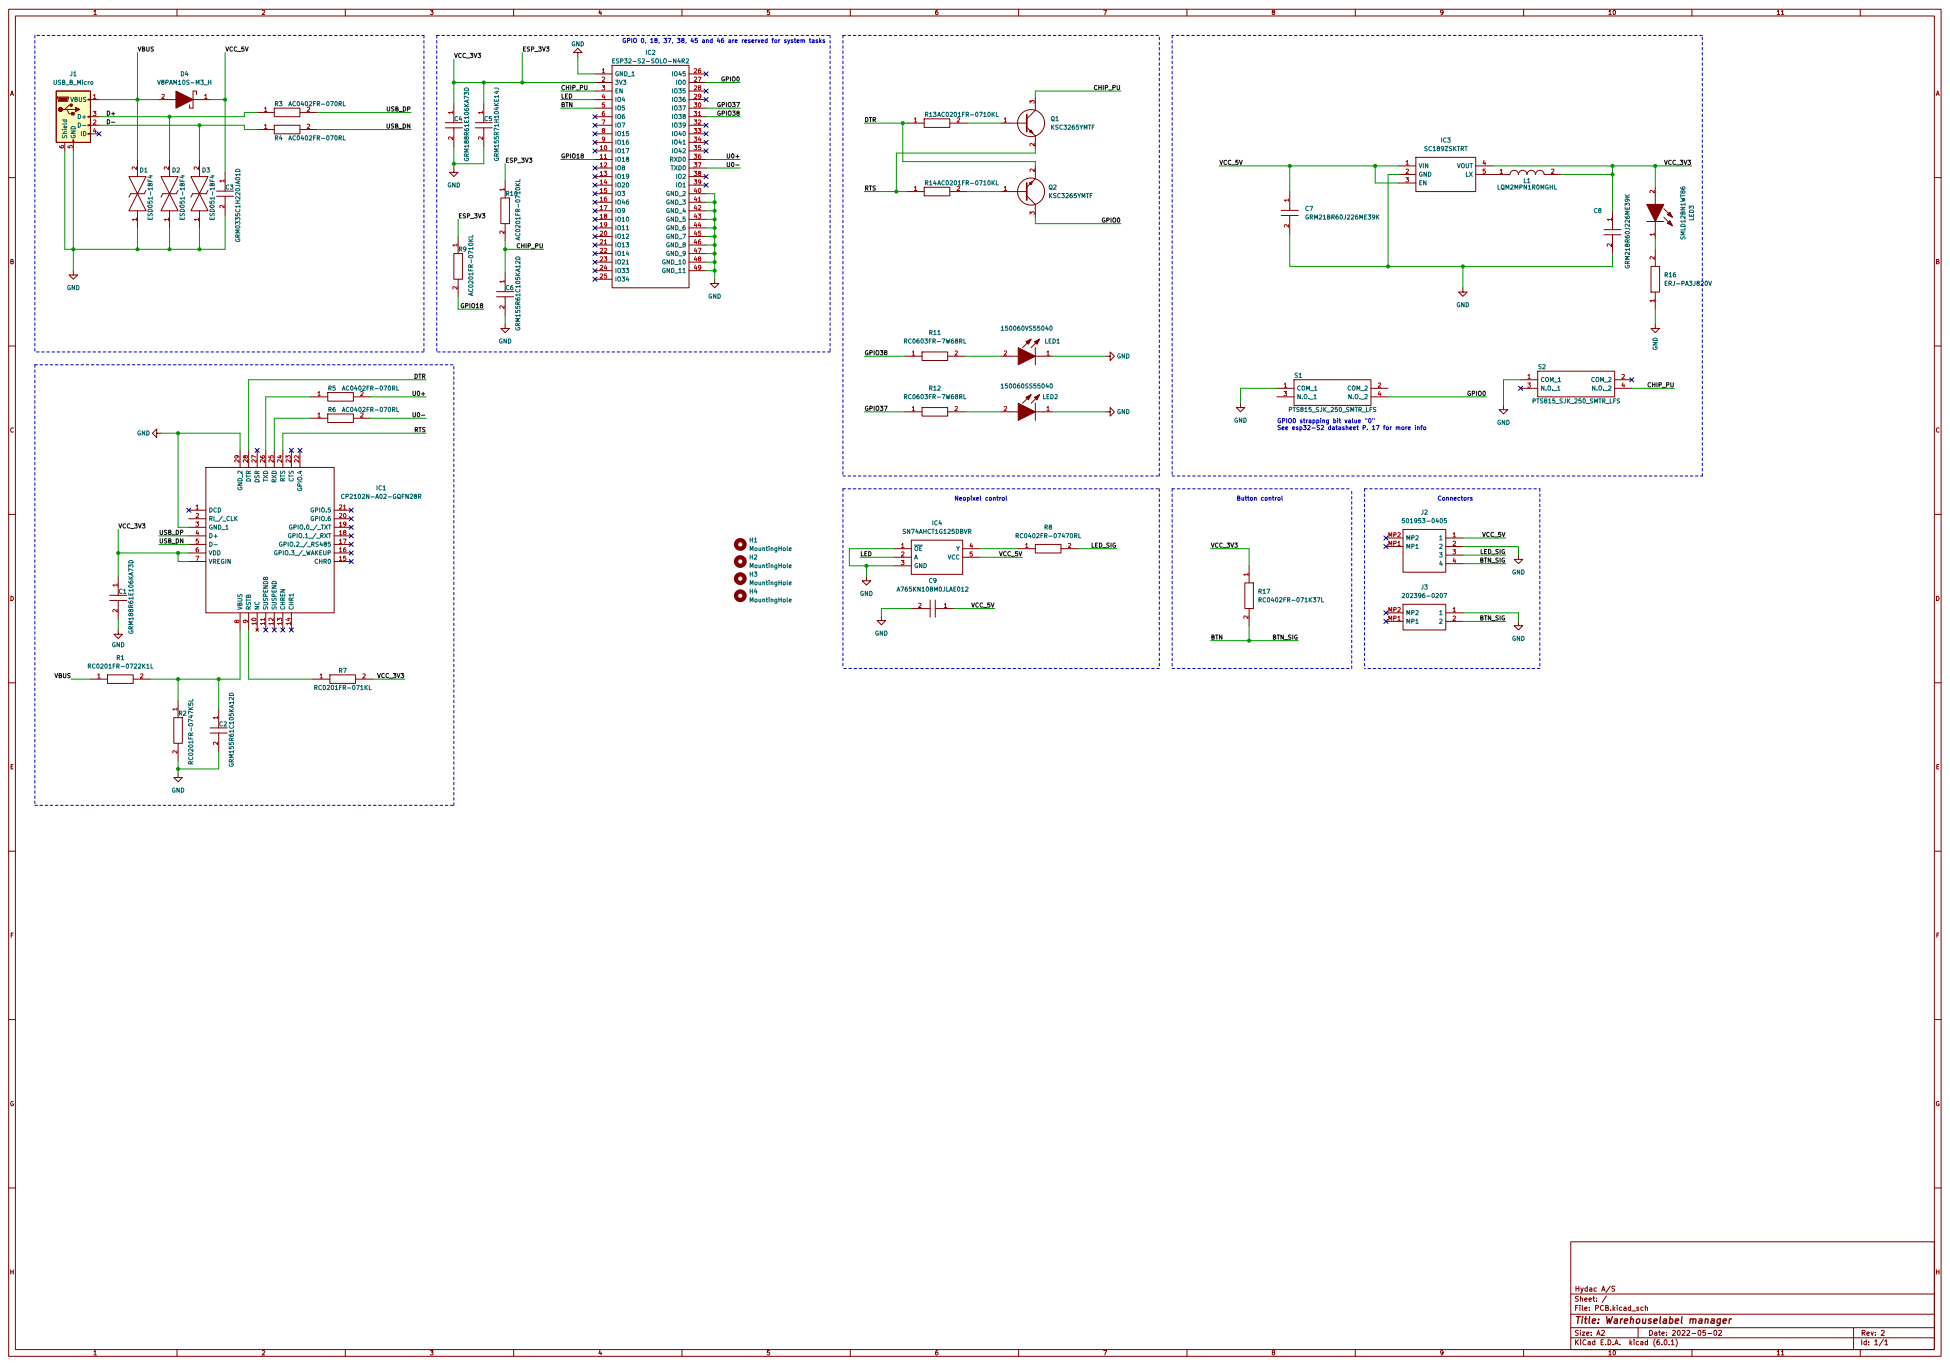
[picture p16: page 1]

GPIO 0, 18, 37, 38, 45 and 46 are reserved for system tasks

GPIO0 strapping bit value "0"
See esp32-S2 datasheet P. 17 for more info

1 2 C1 GRM188R61E106KA73D H4MountingHole H1MountingHole H3MountingHole H2MountingHole DCD 1 NC 10 SUSPENDB 11 SUSPEND 12 CHREN 13 CHR1 14 CHR0 15 GPIO.3_/_WAKEUP 16 GPIO.2_/_RS485 17 GPIO.1_/_RXT 18 GPIO.0_/_TXT 19 RI_/_CLK 2 GPIO.6 20 GPIO.5 21 GPIO.4 22 CTS 23 RTS 24 RXD 25 TXD 26 DSR 27 DTR 28 GND_2 29 GND_1 3 D+ 4 D- 5 VDD 6 VREGIN 7 VBUS

File: PCB.kicad_sch Sheet: / Hydac A/S

Id: 1/1 Title: Warehouselabel manager

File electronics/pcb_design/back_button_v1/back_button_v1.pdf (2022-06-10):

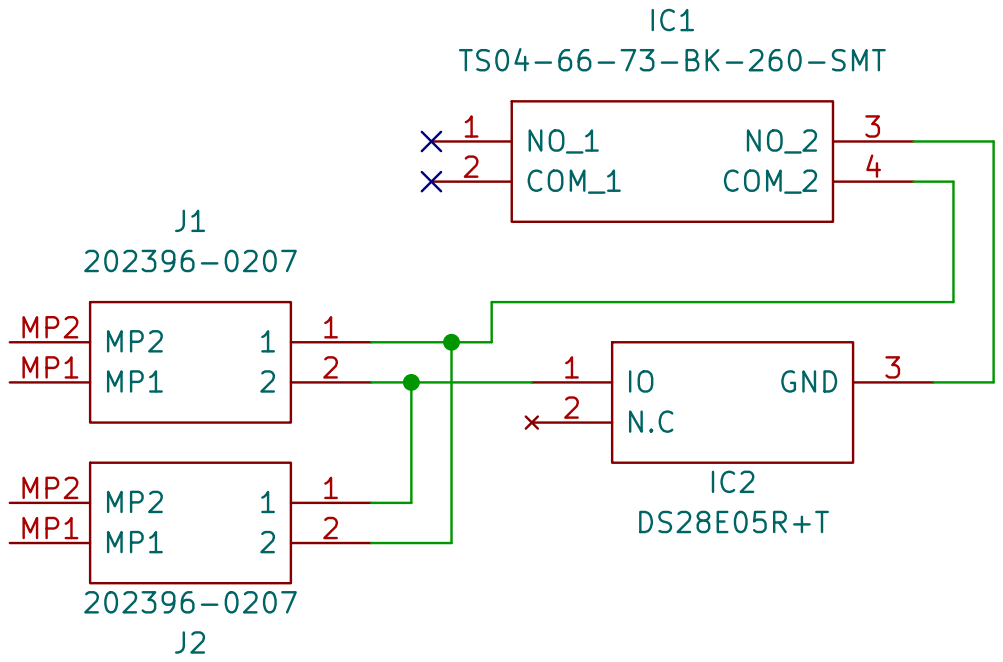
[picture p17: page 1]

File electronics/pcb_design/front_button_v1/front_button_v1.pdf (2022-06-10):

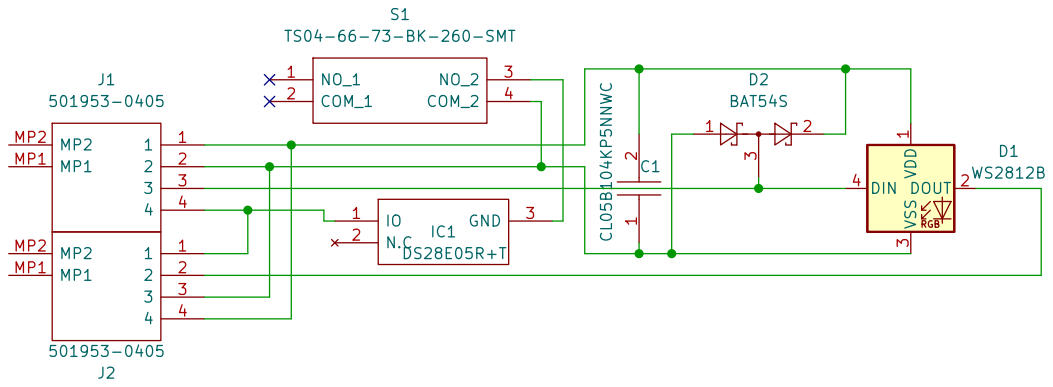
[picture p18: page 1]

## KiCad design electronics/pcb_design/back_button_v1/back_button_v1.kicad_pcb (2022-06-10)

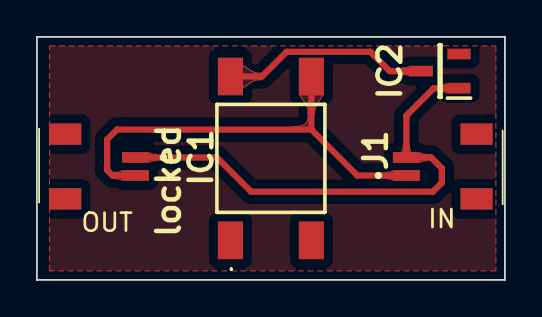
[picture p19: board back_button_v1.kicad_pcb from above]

Board: 2 copper layers, 26.0 x 13.5 mm, 4 parts (0 on the bottom side), 3 nets.

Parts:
IC1: TS04-66-73-BK-260-SMT; TS046673BK160SMT
IC2: DS28E05R+T; SOT95P237X112-3N
J1: 202396-0207; 2023960207
locked: 202396-0207; 2023960207

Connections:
unnamed: IC1.3 (NO_2), IC2.3 (GND)
unnamed: IC1.4 (COM_2), J1.1, locked.2
unnamed: IC2.1 (IO), J1.2, locked.1

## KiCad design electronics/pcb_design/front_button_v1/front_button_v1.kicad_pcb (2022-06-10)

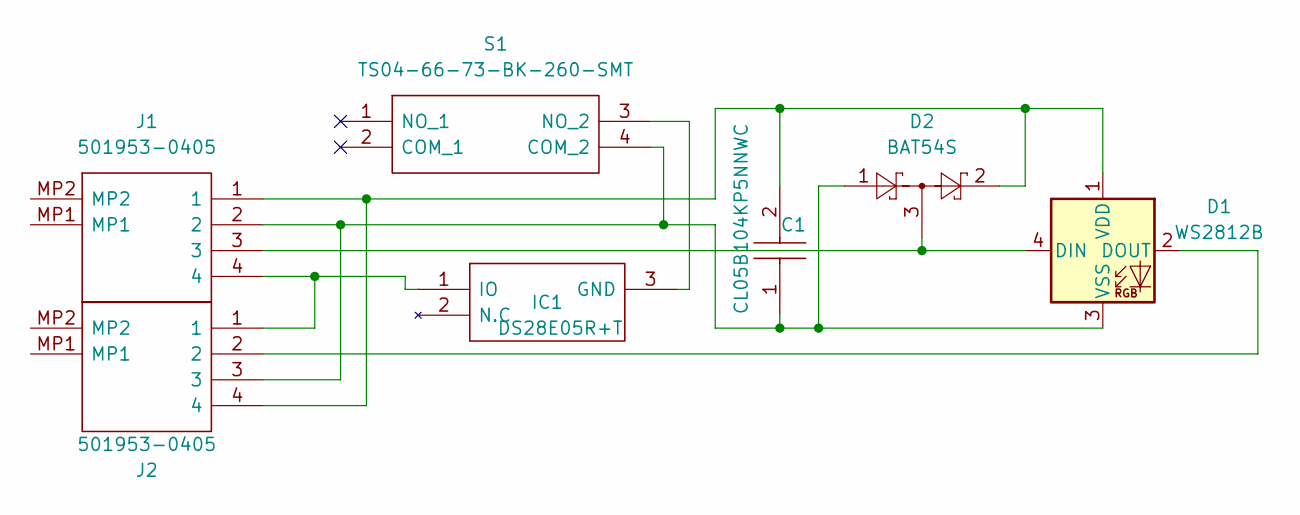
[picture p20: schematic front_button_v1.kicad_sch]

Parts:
C1: CL05B104KP5NNWC; CAPC1005X55N; Manufacturer_Part_Number CL05B104KP5NNWC
D1: WS2812B; LED_WS2812B_PLCC4_5.0x5.0mm_P3.2mm
D2: BAT54S; SOT-23
IC1: DS28E05R+T; SOT95P237X112-3N; Mouser Part Number 700-DS28E05R+T
J1, J2: 501953-0405; 5019530405; Mouser Part Number 538-501953-0405
S1: TS04-66-73-BK-260-SMT; TS046673BK160SMT; Manufacturer_Part_Number TS04-66-73-BK-160-SMT; Mouser Part Number 179-TS046673BK160SMT

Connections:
unnamed: C1.1, D1.3 (VSS), D2.1, J1.2, J2.3, S1.4 (COM_2)
unnamed: C1.2, D1.1 (VDD), D2.2, J1.1, J2.4
unnamed: D1.2 (DOUT), J2.2
unnamed: D1.4 (DIN), D2.3, J1.3
unnamed: IC1.1 (IO), J1.4, J2.1
unnamed: IC1.3 (GND), S1.3 (NO_2)

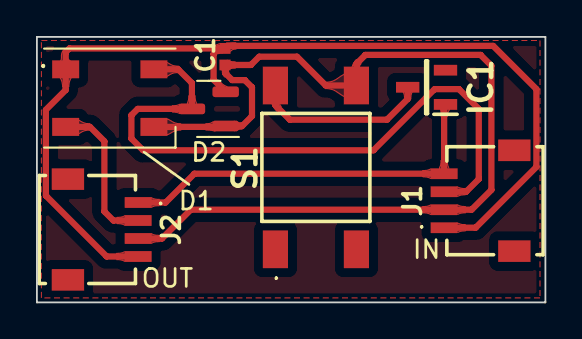
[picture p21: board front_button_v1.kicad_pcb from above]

Board: 2 copper layers, 28.2 x 14.8 mm, 7 parts (0 on the bottom side), 6 nets.

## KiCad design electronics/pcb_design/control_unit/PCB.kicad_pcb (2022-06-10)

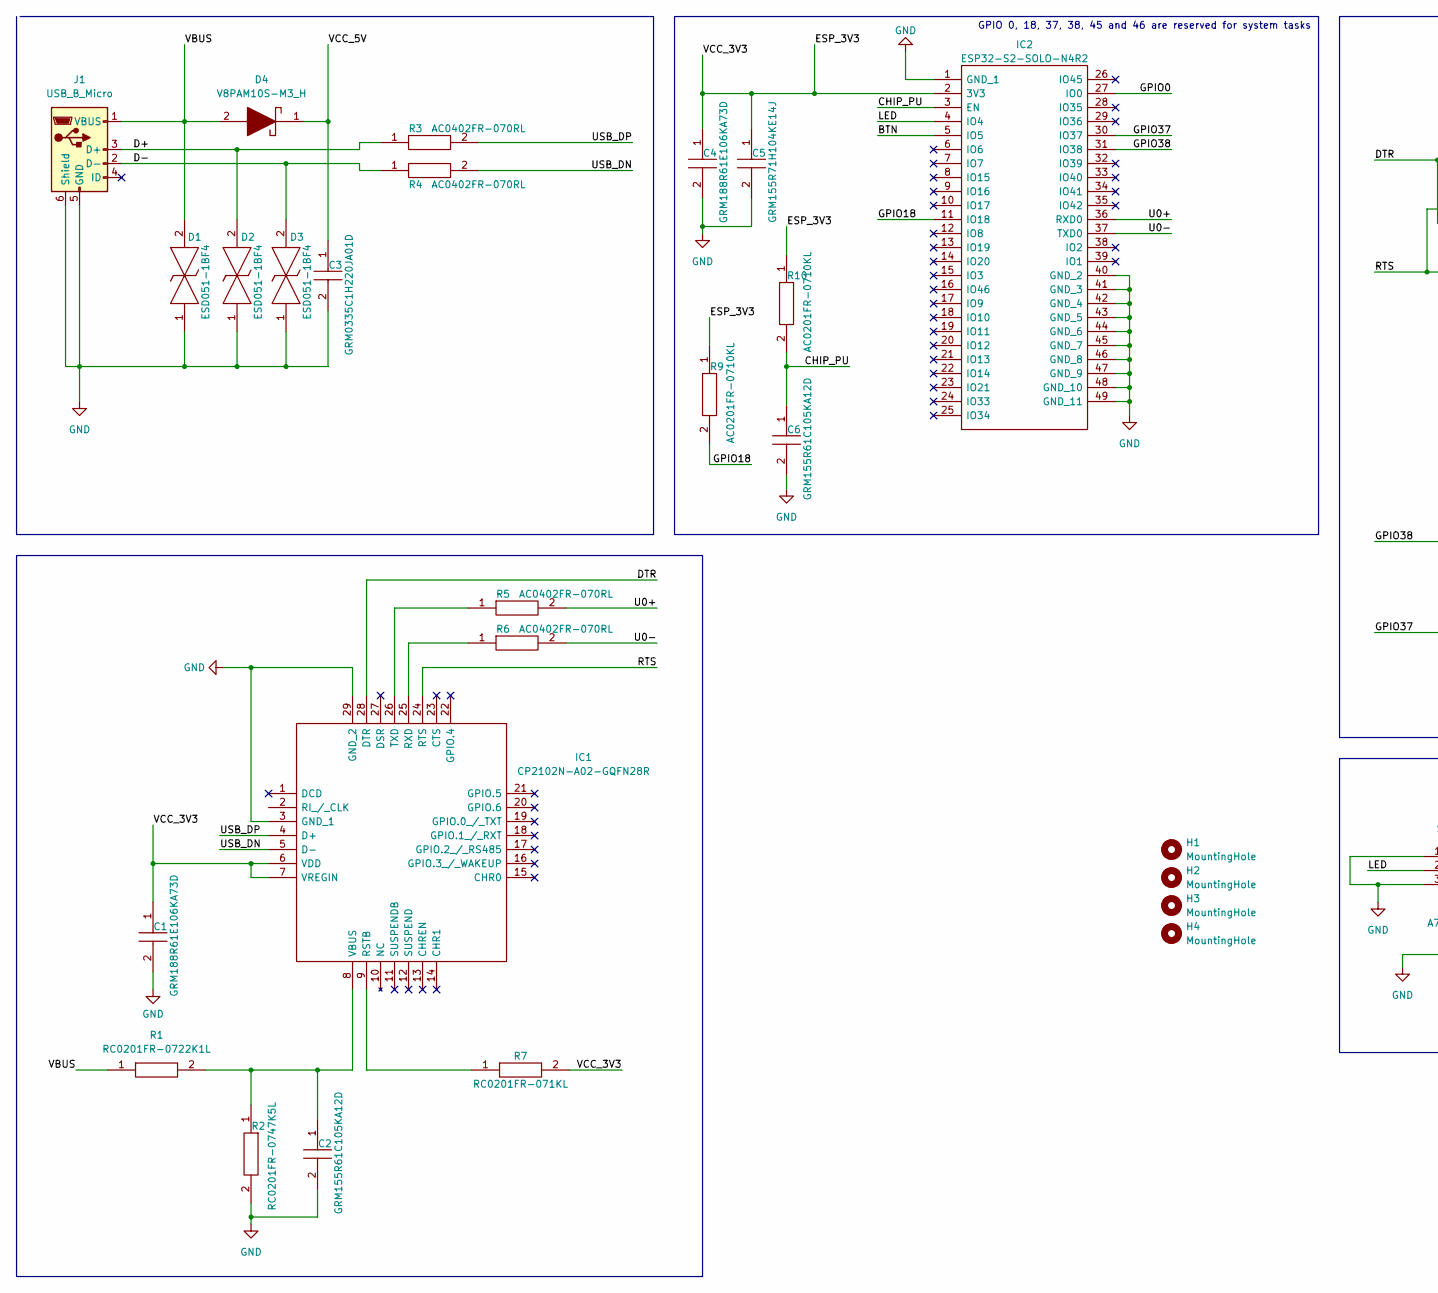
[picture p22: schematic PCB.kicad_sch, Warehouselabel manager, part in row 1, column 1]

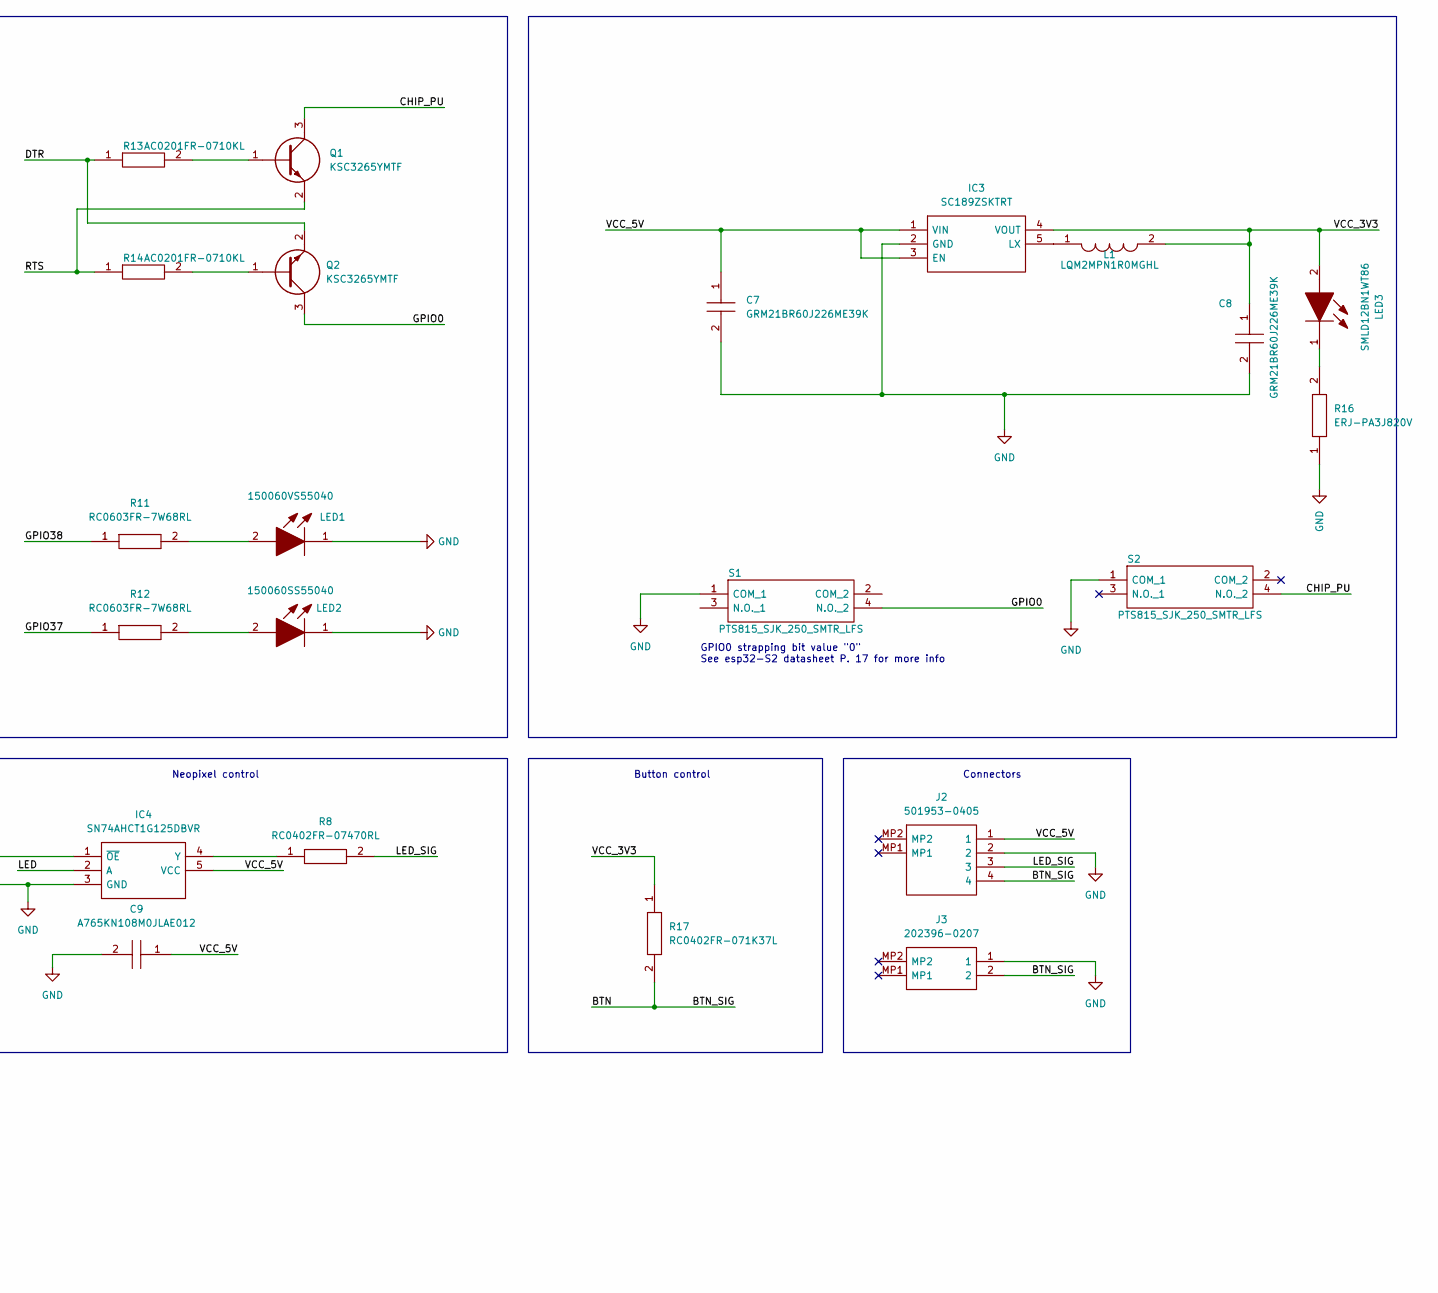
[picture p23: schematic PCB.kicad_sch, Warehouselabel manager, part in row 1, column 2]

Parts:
C1, C4: GRM188R61E106KA73D; CAPC1608X90N; Mouser Part Number 81-GRM188R61E106KA3D
C2, C6: GRM155R61C105KA12D; CAPC1005X55N; Mouser Part Number 81-GRM155R61C105KA2D
C3: GRM0335C1H220JA01D; CAPC0603X33N; Mouser Part Number 81-GRM0335C1H220JA1D
C5: GRM155R71H104KE14J; CAPC1005X55N; Mouser Part Number 81-GRM155R71H104KE4J
C7, C8: GRM21BR60J226ME39K; CAPC2012X140N; Mouser Part Number 81-GRM21BR60J226ME9K
C9: A765KN108M0JLAE012; CAPAE830X1000N; Manufacturer_Part_Number A765KN108M0JLAE012
D1, D2, D3: ESD051-1BF4; ESD0511BF4; Mouser Part Number 511-ESD051-1BF4
D4: V8PAM10S-M3_H; V8PAM10SHM3H; Mouser Part Number 78-V8PAM10S-M3/H
H1, H2, H3, H4: MountingHole; MountingHole_2.7mm_M2.5_ISO7380
IC1: CP2102N-A02-GQFN28R; QFN50P500X500X80-29N-D; Mouser Part Number 634-CP2102NA02QFN28R
IC2: ESP32-S2-SOLO-N4R2; ESP32S2SOLON4R2; Mouser Part Number 356-ESP32-S2SOLON4R2
IC3: SC189ZSKTRT; SOT95P280X145-5N; Mouser Part Number 947-SC189ZSKTRT
IC4: SN74AHCT1G125DBVR; SOT95P280X145-5N; Mouser Part Number 595-SNAHCT1G125DBVR
J1: USB_B_Micro; USB_Micro-B_Amphenol_10104110_Horizontal
J2: 501953-0405; 5019530405; Mouser Part Number 538-501953-0405
J3: 202396-0207; 2023960207; Mouser Part Number 538-202396-0207
L1: LQM2MPN1R0MGHL; LQM2MPN1R0NG0L; Mouser Part Number 81-LQM2MPN1R0MGHL
LED1: 150060VS55040; LEDM168X50N; Mouser Part Number 710-150060VS55040
LED2: 150060SS55040; Mouser Part Number 710-150060SS55040
LED3: SMLD12BN1WT86; LEDM168X65N; Mouser Part Number 755-SMLD12BN1WT86
Q1, Q2: KSC3265YMTF; SOT96P237X111-3N; Mouser Part Number 512-KSC3265YMTF
R1: RC0201FR-0722K1L; RESC0603X26N; Mouser Part Number 603-RC0201FR-0722K1L
R2: RC0201FR-0747K5L; RESC0603X26N; Mouser Part Number 603-RC0201FR-0747K5L
R3, R4, R5, R6: AC0402FR-070RL; RESC1005X37N; Mouser Part Number 603-AC0402FR-070RL
R7: RC0201FR-071KL; RESC0603X26N; Mouser Part Number 603-RC0201FR-071KL
R8: RC0402FR-07470RL; RESC1005X40N; Mouser Part Number 603-RC0402FR-07470RL
R9, R10, R13, R14: AC0201FR-0710KL; RESC0603X26N; Mouser Part Number 603-AC0201FR-0710KL
R11, R12: RC0603FR-7W68RL; RESC1608X55N; Manufacturer_Part_Number RC0603FR-7W68RL
R16: ERJ-PA3J820V; R_0603_1608Metric; Manufacturer_Part_Number ERJ-PA3J820V
R17: RC0402FR-071K37L; RESC1005X40N; Manufacturer_Part_Number RC0402FR-071K37L
S1, S2: PTS815_SJK_250_SMTR_LFS; PTS815SJK250SMTRLFS; Mouser Part Number 611-PTS815SJK250SMTR

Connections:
/BTN: IC2.5 (IO5), J2.4, J3.2, R17.2
/CHIP_PU: C6.1, IC2.3 (EN), Q1.3, R10.2, S2.4 (N.O._2)
/D+: D2.2, J1.3 (D+), R3.1
/D-: D3.2, J1.2 (D-), R4.1
/DTR: IC1.28 (DTR), Q2.2, R13.1
/ESP_3V3: C1.1, C4.1, C5.1, C8.1, IC1.6 (VDD), IC1.7 (VREGIN), IC2.2 (3V3), IC3.4 (VOUT), L1.2, LED3.2, R7.2, R9.1, R10.1, R17.1
/GPIO0: IC2.27 (IO0), Q2.3, S1.4 (N.O._2)
/GPIO18: IC2.11 (IO18), R9.2
/GPIO37: IC2.30 (IO37), R12.1
/GPIO38: IC2.31 (IO38), R11.1
/LED: IC2.4 (IO4), IC4.2 (A)
/LED_SIG: J2.3, R8.2
/RTS: IC1.24 (RTS), Q1.2, R14.1
/U0+: IC2.36 (RXD0), R5.2
/U0-: IC2.37 (TXD0), R6.2
/USB_DN: IC1.5 (D-), R4.2
/USB_DP: IC1.4 (D+), R3.2
/VBUS: D1.2, D4.2, J1.1 (VBUS), R1.1
/VCC_5V: C3.1, C7.1, C9.1, D4.1, IC3.1 (VIN), IC3.3 (EN), IC4.5 (VCC), J2.1
GND: C1.2, C2.2, C3.2, C4.2, C5.2, C6.2, C7.2, C8.2, C9.2, D1.1, D2.1, D3.1, IC1.3 (GND_1), IC1.29 (GND_2), IC2.1 (GND_1), IC2.40 (GND_2), IC2.41 (GND_3), IC2.42 (GND_4), IC2.43 (GND_5), IC2.44 (GND_6), IC2.45 (GND_7), IC2.46 (GND_8), IC2.47 (GND_9), IC2.48 (GND_10), IC2.49 (GND_11), IC3.2 (GND), IC4.1 (~OE), IC4.3 (GND), J1.5 (GND), J1.6 (Shield), J2.2, J3.1, LED1.1, LED2.1, R2.2, R16.1, S1.1 (COM_1), S2.1 (COM_1)
unnamed: C2.1, IC1.8 (VBUS), R1.2, R2.1
unnamed: IC1.9 (RSTB), R7.1
unnamed: IC1.25 (RXD), R6.1
unnamed: IC1.26 (TXD), R5.1
unnamed: IC3.5 (LX), L1.1
unnamed: IC4.4 (Y), R8.1
unnamed: LED1.2, R11.2
unnamed: LED2.2, R12.2
unnamed: LED3.1, R16.2
unnamed: Q1.1, R13.2
unnamed: Q2.1, R14.2

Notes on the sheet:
Button control
Neopixel control
GPIO0 strapping bit value "0" See esp32-S2 datasheet P. 17 for more info
GPIO 0, 18, 37, 38, 45 and 46 are reserved for system tasks
Connectors

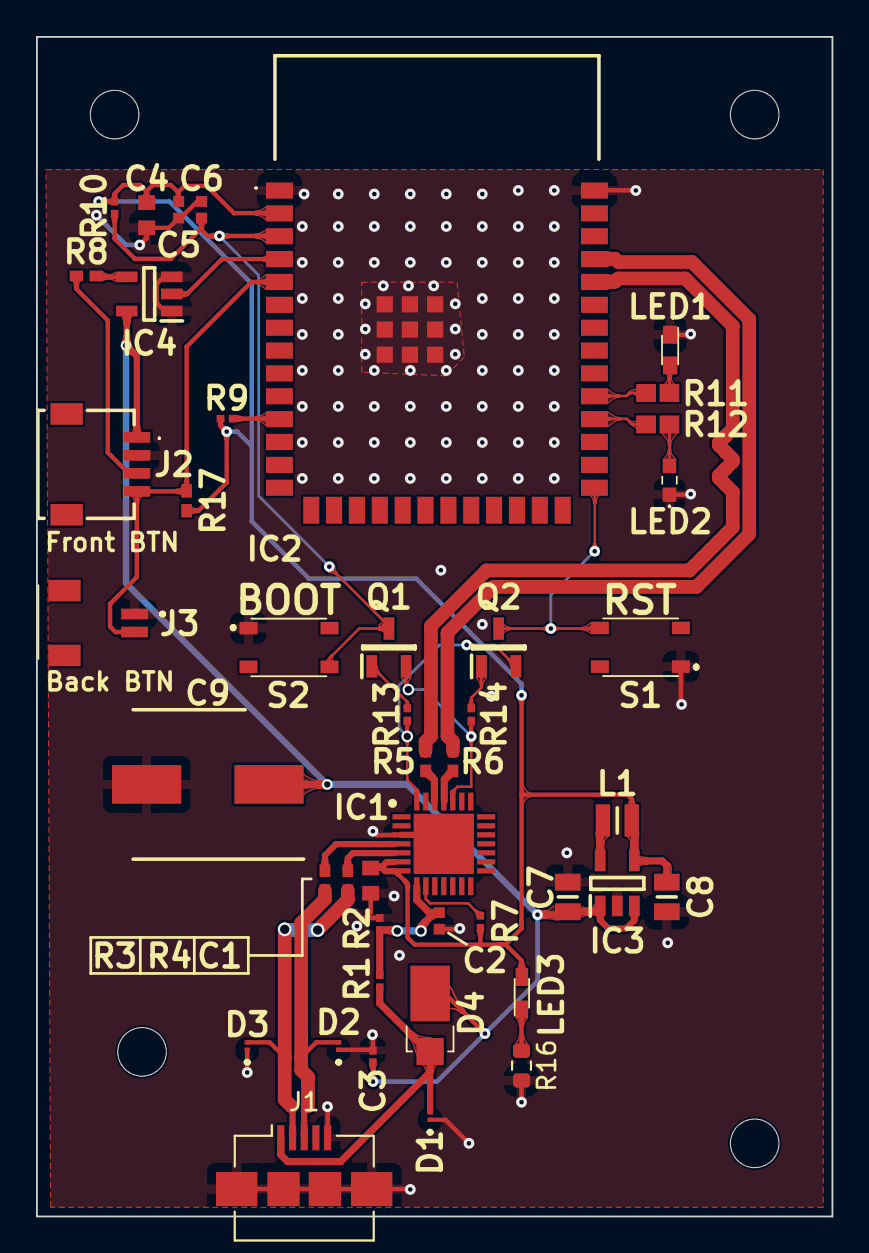
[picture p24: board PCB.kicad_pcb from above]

Board: 2 copper layers, 44.2 x 65.5 mm, 48 parts (0 on the bottom side), 31 nets.

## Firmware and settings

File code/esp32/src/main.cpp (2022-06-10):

#include <Arduino.h>
#include "fileHandler.h"
#include "connectionHandler.h"
#include "buttonHandler.h"

void setup()
{
	Serial.begin(115200);

	FileHandler.init();
	FileHandler.loadConnectionHandlerSettings();
	ConnectionHandler.init();
  ButtonHandler.init();
}

const long interval = 100;		   // interval at which to blink (milliseconds)
unsigned long previousMillis = 0;  // will store last time LED was updated
const long interval2 = 1000;	   // interval at which to blink (milliseconds)
unsigned long previousMillis2 = 0; // will store last time LED was updated

void loop()
{
	unsigned long currentMillis = millis();
	ConnectionHandler.wifiConnecAsync();

	if (ConnectionHandler.wifiConnected())
	{
		ConnectionHandler.mqttConnect();
		if (ConnectionHandler.mqttConnected())
		{
			if (ConnectionHandler.sendTopic == ConnectionHandler.setupSend)
				{
					ButtonHandler.systemState = ButtonHandler.systemSetup;
				}
			else 
			{
				ButtonHandler.systemState = ButtonHandler.systemOperating;
			}
			switch (ButtonHandler.systemState)
			{
			case ButtonHandler.systemOperating:
				if (ButtonHandler.btnChecker())
				{
					if (currentMillis - previousMillis2 >= interval2)
					{
						previousMillis2 = currentMillis;
            			Serial.println("Sending mqtt message");
						ConnectionHandler.sendMQTT();
					}
          			Serial.println("Updating LEDs");
					ButtonHandler.LEDUpdate();
				}
				break;
			case ButtonHandler.systemSetup:
				ButtonHandler.btnSetup();
				break;
			}
		}
	}
}

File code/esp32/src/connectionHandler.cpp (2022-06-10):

#include <Arduino.h>

#include <WiFi.h> // Go through code and update wifi stuff
#include "connectionHandler.h"
#include "PubSubClient.h"
#include "buttonHandler.h"
#include <string>

ConnectionHandlerClass ConnectionHandler;
WiFiClient espClient;
PubSubClient client(espClient);

void ConnectionHandlerClass::init()
{
    pinMode(WiFiLED, OUTPUT);
    pinMode(MQTTLED, OUTPUT);
    int numSsid = WiFi.scanNetworks();
    if (numSsid == -1) {
      Serial.println("Couldn't get a wifi connection");
      while (true);
    }

    // print the list of networks seen:
    Serial.print("number of available networks:");
    Serial.println(numSsid);

    // print the network number and name for each network found:
    for (int thisNet = 0; thisNet < numSsid; thisNet++) {
      Serial.print(thisNet);
      Serial.print(") ");
      Serial.print(WiFi.SSID(thisNet));
      Serial.print("\tSignal: ");
      Serial.print(WiFi.RSSI(thisNet));
      Serial.print(" dBm");
    }
}

void ConnectionHandlerClass::wifiConnecAsync()
{
    uint32_t ts = millis();
    if (ts > (wifiLastAttempt + wifiReconnect_interval) || wifiLastAttempt == 0)
    {
        wifiLastAttempt = ts;

        switch (wifiConnectionState)
        {
        case WifiNotConnected:
            // connect to the network
            WiFi.begin(settings.SSID, settings.WiFiPassword);
            wifiReconnect_interval = 200;
            wifiConnectionState = WifiConnecting;
            break;
        case WifiConnecting:
            // Wait for connection
            if (WiFi.status() == WL_CONNECTED)
            {
                wifiReconnect_interval = 10000;
                wifiConnectionState = WifiConnected;
                Serial.println("\nConnected to WiFi.");
            }

            Serial.print(".");
            wifiSubAttempts++;
            if (wifiSubAttempts >= 50)
            {
                // We have waited for a long time, send an error and try again
                Serial.println();
                wifiAttempt++;
                wifiSubAttempts = 0;
                Serial.printf("Failed to connect to WiFi on attempt: %d.\n\n", wifiAttempt);
                Serial.println("to SSID: " + String(settings.SSID) + " with pass: " + String(settings.WiFiPassword));
                wifiConnectionState = WifiNotConnected;
            }
            break;
        case WifiConnected:
            // All good, check that we have not been disconnected
            if (WiFi.status() != WL_CONNECTED)
            {
                wifiReconnect_interval = 200;
                wifiConnectionLosses++;
                wifiConnectionState = WifiNotConnected;
                wifiAttempt = 0;
                Serial.println("Disconnected from WiFi.");
                Serial.printf("Connection status: %d\n", WiFi.status());
                digitalWrite(WiFiLED, LOW);
            }
            digitalWrite(WiFiLED, HIGH);
            break;
        default:
            wifiReconnect_interval = 200;
            wifiConnectionState = WifiNotConnected;

            break;
        }
    }
}

bool ConnectionHandlerClass::wifiConnected()
{
    return wifiConnectionState == WifiConnected;
    Serial.println(macAdd);
}
void ConnectionHandlerClass::callback(char *topic, uint8_t *payload, unsigned int length)
{
    if ((char)payload[0] == '1')
    {
        sendTopic = setupSend;
    }
    else
    {
        sendTopic = order;
    }
}
void ConnectionHandlerClass::mqttConnect()
{
    client.setServer(settings.MQTTBroker.c_str(), settings.MQTTPort);
    client.setCallback(std::bind(&ConnectionHandlerClass::callback, this, std::placeholders::_1, std::placeholders::_2, std::placeholders::_3));
    client.setKeepAlive(60);
    client.setSocketTimeout(30);
    uint32_t ts = millis();
    if (ts > (mqttLastAttempt + mqttReconnect_interval) || mqttLastAttempt == 0)
    {
        mqttLastAttempt = ts;

        switch (mqttConnectionState)
        {
        case MqttNotConnected:
            // connect to the MQTT broker
            Serial.print("Broker ");
            Serial.println(settings.MQTTBroker.c_str());
            Serial.print("Port ");
            Serial.println(settings.MQTTPort);
            Serial.print("Client Id ");
            Serial.println(clientId.c_str());
            client.connect(clientId.c_str(), settings.MQTTUsername.c_str(), settings.MQTTPassword.c_str());
            mqttReconnect_interval = 200;
            mqttConnectionState = MqttConnecting;
            break;
        case MqttConnecting:
            // Wait for connection
            if (client.connected() == true)
            {
                mqttReconnect_interval = 10000;
                mqttConnectionState = MqttConnected;
                Serial.println("\nConnected to MQTT.");
                client.subscribe(setupReceive.c_str());
            }

            Serial.print(".");
            mqttSubAttempts++;
            if (mqttSubAttempts >= 50)
            {
                // We have waited for a long time, send an error and try again
                Serial.println();
                mqttAttempt++;
                mqttSubAttempts = 0;
                Serial.printf("Failed to connect to MQTT broker on attempt: %d.\n\n", mqttAttempt);
                Serial.println("");
                Serial.println("MQTT state:" + String(client.state()));
                mqttConnectionState = MqttNotConnected;
            }
            break;
        case MqttConnected:
            // All good, check that we have not been disconnected
            if (client.state() != 0)
            {
                mqttReconnect_interval = 200;
                mqttConnectionLosses++;
                mqttConnectionState = MqttNotConnected;
                mqttAttempt = 0;
                Serial.printf("Disconnected from MQTT broker. Returns client state: %d.\n\n", client.state());
                digitalWrite(MQTTLED, LOW);
            }
            digitalWrite(MQTTLED, HIGH);
            client.loop();
            break;
        default:
            mqttReconnect_interval = 200;
            mqttConnectionState = MqttNotConnected;

            break;
        }
    }
}

bool ConnectionHandlerClass::mqttConnected()
{
    return mqttConnectionState == MqttConnected;
}

void ConnectionHandlerClass::sendMQTT()
{
    if (ButtonHandler.btnChecker() != 0)
    {
        String messageConstruct = ButtonHandler.buttonSN + " " + macAdd;
        client.publish(sendTopic.c_str(), messageConstruct.c_str());
    }
}
